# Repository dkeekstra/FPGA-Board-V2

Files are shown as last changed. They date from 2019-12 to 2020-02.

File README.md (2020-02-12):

# FPGA Board V2
## Key Features:
* Intel Cyclone 10 
* 16k logic elements
* Onboard usb programmer
* 3x 2.5khz to 200MHz programmable clock
* 4Mb on board configuration memory
* 40pin GPIO header
* USB OTG and HDMI connector
* RS485
* 8x User leds
* 5x User push buttons
* 4x User dip switches

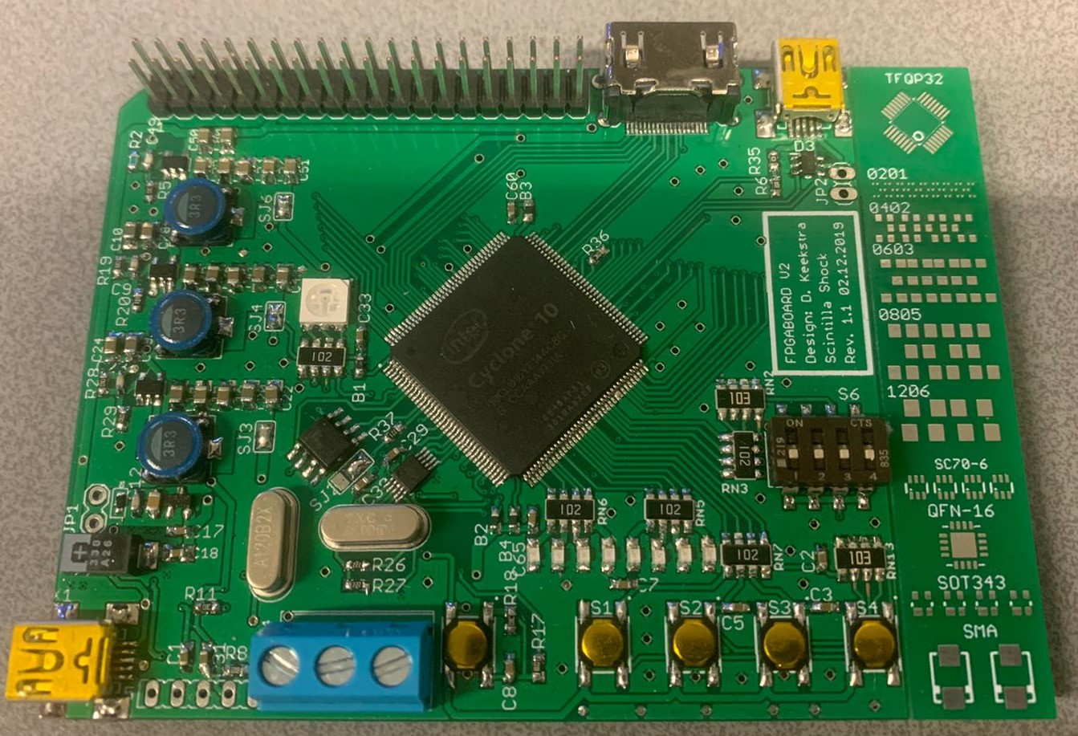
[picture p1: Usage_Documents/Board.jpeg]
FPGA BOARD


By D. Keekstra

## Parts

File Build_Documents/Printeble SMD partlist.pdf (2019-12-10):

33 | 100nF | C0603
4 | 16pF | C0603
4 | 22pF | C0603
22 | 10uF X5R | C0805K
1 | 330uF | big
1 | 100R | R0603
2 | 10 | R0603
8 | 10k | R0603
2 | 100k | R0603
2 | 1k | R0603
1 | 200R | R0603
1 | 150k | R0603
1 | 120R | R0603
1 | 32k | R0603
1 | 33k | R0603
2 | 2k2 | R0603
4 | 0 | R0603
5 | 1k | 744-8NS
2 | 10k | 744-8NS
6 | B-EU | C0603
1 | NTR2101P | SOT23-3
1 | Bi TVS 5V | SOD-523
2 | IP4234CZ6,125 | SOT95-6N
1 | OVSTRGBBCR8
9 | Any color | 0805
5 | DTSM-6 | DTSM-6
1 | OSCILLATOR 5X3 | 5X3
1 | SI5351A | MSOP-10
3 | AP3429 | TSOT-25
1 | IS25LQ040B-JNLE | SOIC8
1 | Any 3.3v rs485 | SO-08
1 | PIC18F14K50-I/SS | SOP20

SMD Partlist

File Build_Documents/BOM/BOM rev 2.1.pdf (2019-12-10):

Type | Qty | Value | Device | Package | Parts | Description | MOUSER | Discription | Stores | Price | Price Total | Checked | Order Description | Aantal Totaal | Prijs Totaal | Aantal orders
CAP | 33 | 100nF | C-EUC0603 | C0603 | C1, C2, C3, C5, C7, C8, C11, C13, C17, C27, C28, C29, C30, C31, C32, C33, C34, C35, C36, C37, C38, C39, C40, C44, C45, C46, C47, C58, C59, C60, C61, C64, C65 CAPACITOR, European symbol | 710-885012206071 | ? | 0.04 | 1.32 | x | 825 | €33.00 | 25
| 4 | 16pF | C-EUC0603 | C0603 | C4, C6, C81, C82 | CAPACITOR, European symbol | 603-CC603JRNPO0BN160 | | ? | 0.09 | 0.36 | x | | 100 | €9.00
| 4 | 22pF | C-EUC0603 | C0603 | C9, C12, C23, C49 | CAPACITOR, European symbol | 581-06035C220JAT2A | | ? | 0.18 | 0.72 | x | | 100 | €18.00
| 22 | 10uF X5R | C-EUC0805K | C0805K | C10, C14, C15, C16, C18, C20, C22, C24, C25, C26, C41, C42, C43, C50, C51, C52, C53, C54, C55, C78, C79, C80 CAPACITOR, European symbol | | | | x | 0 | 0 | x | | 550 | €0.00
| | | | | | | | | | | | | | 0 €0.00
Cap Pol | 1 | 330uF 10V (10tpe330m) | CPOL-EUD/7343-31W | D/7343-31W | C21 | POLARIZED CAPACITOR, European symbol | | | x | 0 | 0 | x | | 25 | €0.00
| | | | | | | | | | | | | | 0 €0.00
Resistor | 1 | 100R | R-EU_R0603 | R0603 | R35 | RESISTOR, European symbol | 754-RR0816P-101D | | ? | 0.014 | 0.014 | x | min 100st | 25 | €0.35
| 2 | 10 | R-EU_R0603 | R0603 | R21, R22 | RESISTOR, European symbol | 754-RR0816Q-100D | | ? | 0.014 | 0.028 | x | min 100st | 50 | €0.70
| 8 | 10k | R-EU_R0603 | R0603 | R5, R11, R18, R24, R25, R33, R34, R36 RESISTOR, European symbol | | 603-RT0603FRE0710KL | | ? | 0.014 | 0.112 | x | min 100st | 200 | €2.80
| 2 | 100k | R-EU_R0603 | R0603 | R28, R29 | RESISTOR, European symbol | 754-RR0816P-104D | | ? | 0.014 | 0.028 | x | min 100st | 50 | €0.70
| 2 | 1k | R-EU_R0603 | R0603 | R8, R17 | RESISTOR, European symbol | 603-RT0603FRE071KL | | ? | 0.014 | 0.028 | x | min 100st | 50 | €0.70
| 1 | 200R | R-EU_R0603 | R0603 | R6 | RESISTOR, European symbol | 667-ERA-3AED201V | | ? | 0.027 | 0.027 | x | min 100st | 25 | €0.68
| 1 | 150k | R-EU_R0603 | R0603 | R19 | RESISTOR, European symbol | 667-ERA-3AED154V | | | 0.037 | 0.037 | x | min 100st | 25 | €0.93
| 1 | 120R | R-EU_R0603 | R0603 | R23 | RESISTOR, European symbol | 603-RT0603DRE07120RL | | ? | 0.022 | 0.022 | x | min 100st | 25 | €0.55
| 1 | 32k | R-EU_R0603 | R0603 | R2 | RESISTOR, European symbol | 603-RT0603BRD0732KL | | | 0.211 | 0.211 | x | | 25 | €5.28
| 1 | 33k | R-EU_R0603 | R0603 | R20 | RESISTOR, European symbol | 603-RT0603DRE0733KL | | | 0.023 | 0.023 | x | min 100st | 25 | €0.58
| 2 | 2k2 | R-EU_R0603 | R0603 | R26, R27 | RESISTOR, European symbol | 603-RT0603DRE072K2L | | ? | 0.022 | 0.044 | x | min 100st | 50 | €1.10
| 4 | 0 | R-EU_R0603 | R0603 | R1, R3, R4, R12 | RESISTOR, European symbol | 71-RCS06030000Z0EA | | ? | 0.014 | 0.056 | x | min 100st | 100 | €1.40
| | | | | | | | | | | | | | 0 €0.00
Res Array | 5 | 1k | 744-8NS | 744-8NS | RN1, RN3, RN5, RN6, RN7 | CTS 744 Series | 660-CN2B4TTE102J | | | 0.151 | 0.755 | x | | 125 | €18.88
| 2 | 10k | 744-8NS | 744-8NS | RN2, RN13 | CTS 744 Series | 660-CN2B4TTE103J | | | 0.151 | 0.302 | x | | 50 | €7.55
| | | | | | | | | | | | | | 0 €0.00
Ferrite Beads | 6 | B-EU | B-EU | C0603 | B1, B2, B3, B4, B5, B6 | Standart ferrite beads 100mhz 0603 2A | 81-BLM18KG221SN1D | | | 0.09 | 0.54 | x | | 150 | €13.50
| | | | | | | | | | | | | | 0 €0.00
Coil | 3 | 3.3uH 1.9A PWR | SLF7032T3R3M1R9-2-PF | SLF7032T | L2, L3, L4 | inductor SLF7032T | SLF7032T-3R3M1R9-2-PF | | x | | 0 | | | 75 | €0.00
| | | | | | | | | | | | | | 0 €0.00
Xtal | 1 | 12MHz | XTAL/S | QS | Q1 | CRYSTAL | 549-CYS6Q31C-12MHZ | | | 0.9 | 0.9 | x | | 25 | €22.50
| 1 | 25MHz | XTAL/S | QS | Q2 | CRYSTAL | 717-9B-25.000MBBK-B | | | 0.26 | 0.26 | x | | 25 | €6.50
| | | | | | | | | | | | | | 0 €0.00
Mosfet | 1 | NTR2101P | MOSFET-PCHANNELIRLML2244 | SOT23-3 | Q3 | Generic PMOSFET | 863-NTR2101PT1G | | | 0.33 | 0.33 | x | | 25 | €8.25
| | | | | | | | | | | | | | 0 €0.00
TVS | 1 | Bi TVS 5V | DIODESOD-523 | SOD-523 | D1 | Diode | 750-CPDH5V0P-HF | | | 0.25 | 0.25 | x | | 25 | €6.25
| 2 | IP4234CZ6,125 | IP4234CZ6,125 | SOT95P275X110-6N | D2, D3 | TVS DIODE 5.5VWM 6TSOP | 771-IP4234CZ6125 | | | 0.35 | 0.7 | x | | 50 | €17.50
| | | | | | | | | | | | | | 0 €0.00
Leds | 1 | OVSTRGBBCR8 | OVSTRGBBCR8 | 150505M173300 | LED9 | RGB Wurth Elektronik led | 710-150505M173300 | | | 0.522 | 0.522 | x | | 25 | €13.05
| 9 | Any color | LEDCHIP-LED0805 | CHIP-LED0805 | LED0, LED1, LED2, LED3, LED4, LED5, LED6, LED7, USB_BLASTER LED | | 604-AP2012HD | | | 0.18 | 1.62 | x | | 225 | €40.50
| | | | | | | | | | | | | | 0 €0.00
Headers | 1 | | PINHD-1X2 | 1X02 | JP2 | PIN HEADER | | Not Placed | x | | 0 | x | | 25 | €0.00
| 1 | GPIO Header | MA20-2 | MA20-2 | SV1 | PIN HEADER | 649-68691-440HLF | | | 0.99 | 0.99 | x | | 25 | €24.75
| 1 | Pickit2 | MA06-1 | MA06-1 | SV3 | PIN HEADER | | Not Placed | | | 0 | x | | 25 | €0.00
| 1 | VIN | M02JST-PTH-VERT | JST-2-PTH-VERT | JP1 | Standard 2-pin 0.1 header. Use with" | | Not Placed | | | 0 | x | | 25 | €0.00
| | | | | | | | | | | | | | 0 €0.00
Switches | 5 | DTSM-6 | DTSM-6 | DTSM-6 | RESET, S1, S2, S3, S4 | | 611-PTS526SM08SMTR2L | | | 0.099 | 0.495 | x | | 125 | €12.38
| 1 | SWS004 | SWS004 | SMS-004 | S6 | SMD Dip Switch 4 pol. | 774-219-4LPS | | | 0.648 | 0.648 | x | | 25 | €16.20
| | | | | | | | | | | | | | 0 €0.00
Connectors | 1 | | W237-3E | W237-3E | RS485 | WAGO SREW CLAMP | 538-39880-4303 | | | 0.819 | 0.819 | x | | 25 | €20.48
| 2 | MINI-USB-32005-201 | MINI-USB-32005-201 | 32005-201 | X2, X3 | MINI USB-B Conector | 490-UJ2-MBH-1-SMT | | | 0.441 | 0.882 | x | | 50 | €22.05
| 1 | HDMI | HDMI | HDMI_A | U$9 | Horizonal HDMI type A" jack" | 649-10029449-111RLF | | | 0.648 | 0.648 | x | | 25 | €16.20
| | | | | | | | | | | | | | 0 €0.00
IC's | 1 | OSCILLATOR 5X3 | OSCILLATOR 5X3 | CRYSTAL-OSC-SMD-5X3 | U2 | Generic 5x3 and 7x5 oscillators | 972-LH535048.000000I | | | 0.9 | 0.9 | x | | 25 | €22.50
| 1 | SI5351A | SI5351A_CLOCK_GEN | MSOP-10 | U1 | CLOCK GENERATOR | 634-SI5351A-B-GT | | | 1.04 | 1.04 | x | | 25 | €26.00
| 1 | 10CL016YE144C8G | 10CL016YE144C8G | QFP50P2200X2200X165-145N | IC1 | FPGA - Field Programmable Gate Array | | | Free :) | 0 | 0 | x | | 25 | €0.00
| 3 | AP3429 | AP3429 | TSOT-25 | U$3, U$7, U$11 | Switch Power | 621-AP3429AKTTR-G1 | | | 0.369 | 1.107 | x | | 75 | €27.68
| 1 | IS25LQ040B-JNLE | IS25LQ040B-JNLE | SOIC8 | U4 | FPGA Flash | 870-25LQ040BJNLE | | | 0.333 | 0.333 | x | | 25 | €8.33
| 1 | Any 3.3v rs485 | SN65176D | SO-08 | IC2 | DIFFERENTIAL BUS TRANSCEIVER | 511-ST3485EIDT | | | 1.65 | 1.65 | x | | 25 | €41.25
| 1 | PIC18F14K50-I/SS | PIC18F14K50-I/SS | SOP65P780X200-20N | U3 | Flash Microcontrollers | 579-PIC18F14K50-I/SS | | | 2 | 2 | x | | 25 | €50.00
| | | | | | | | | | | | | | 0 €0.00
| | | | | | | | | | | 0 | | | 0 | €0.00
Misc | 1 | PCB | | | | | | | | 0 | 0 | x | | 25 | €0.00
| 1 | USB Cable | | | | | 530-SC-2ANK003F | | ? | 1.94 | 1.94 | x | | 25 | €48.50
| 5 | Bumper | | | | | 517-SJ-5003GY | | | 0.099 | 0.495 | | | 125 | €12.38
| | | | | | | | | | Total | 23.156 | | | | €578.90

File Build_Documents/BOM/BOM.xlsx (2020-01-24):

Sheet: Sorted Full BOM
Type | Qty | Value | Device | Package | Parts | Description | MOUSER | Discription | Stores | Price | Price Total | Checked | Order Description | Aantal Totaal | Prijs Totaal | Aantal orders
CAP | 33 | 100nF | C-EUC0603 | C0603 | C1, C2, C3, C5, C7, C8, C11, C13, C17, C27, C28, C29, C30, C31, C32, C33, C34, C35, C36, C37, C38, C39, C40, C44, C45, C46, C47, C58, C59, C60, C61, C64, C65 | CAPACITOR, European symbol |  |  | Tray7 4a | 0 | 0 | x |  | 825 | €0.00 | 25
 | 4 | 16pF | C-EUC0603 | C0603 | C4, C6, C81, C82 | CAPACITOR, European symbol |  |  | Tray5 7a | 0 | 0 | x |  | 100 | €0.00
 | 4 | 22pF | C-EUC0603 | C0603 | C9, C12, C23, C49 | CAPACITOR, European symbol |  |  | Tray5 9a | 0 | 0 | x |  | 100 | €0.00
 | 22 | 10uF X5R | C-EUC0805K | C0805K | C10, C14, C15, C16, C18, C20, C22, C24, C25, C26, C41, C42, C43, C50, C51, C52, C53, C54, C55, C78, C79, C80 | CAPACITOR, European symbol |  |  | Tray7 5h | 0 | 0 | x |  | 550 | €0.00
 |  |  |  |  |  |  |  |  |  |  |  |  |  | 0 | €0.00
Cap Pol | 1 | 330uF 10V (10tpe330m) | CPOL-EUD/7343-31W | D/7343-31W | C21 | POLARIZED CAPACITOR, European symbol |  |  | SMD rol | 0 | 0 | x |  | 25 | €0.00
 |  |  |  |  |  |  |  |  |  |  |  |  |  | 0 | €0.00
Resistor | 1 | 100R | R-EU_R0603 | R0603 | R35 | RESISTOR, European symbol |  |  | Tray3 6a | 0 | 0 | x |  | 25 | €0.00
 | 2 | 10 | R-EU_R0603 | R0603 | R21, R22 | RESISTOR, European symbol | 754-RR0816Q-100D |  |  | 0.09 | 0.18 | x |  | 50 | €4.50
 | 8 | 10k | R-EU_R0603 | R0603 | R5, R11, R18, R24, R25, R33, R34, R36 | RESISTOR, European symbol |  |  | Tray3 11a | 0 | 0 | x |  | 200 | €0.00
 | 2 | 100k | R-EU_R0603 | R0603 | R28, R29 | RESISTOR, European symbol |  |  | Tray4 4g | 0 | 0 | x |  | 50 | €0.00
 | 2 | 1k | R-EU_R0603 | R0603 | R8, R17 | RESISTOR, European symbol |  |  | Tray3 9h | 0 | 0 | x |  | 50 | €0.00
 | 1 | 200R | R-EU_R0603 | R0603 | R6 | RESISTOR, European symbol | 667-ERA-3AED201V |  |  | 0.05 | 0.05 | x |  | 25 | €1.25
 | 1 | 150k | R-EU_R0603 | R0603 | R19 | RESISTOR, European symbol | 667-ERA-3AED154V |  |  | 0.097 | 0.097 | x |  | 25 | €2.43
 | 1 | 120R | R-EU_R0603 | R0603 | R23 | RESISTOR, European symbol | 603-RT0603DRE07120 |  |  | 0.064 | 0.064 | x |  | 25 | €1.60
 | 1 | 32k | R-EU_R0603 | R0603 | R2 | RESISTOR, European symbol | RN731JTTD3202D25 |  |  | 0.151 | 0.151 | x |  | 25 | €3.77
 | 1 | 33k | R-EU_R0603 | R0603 | R20 | RESISTOR, European symbol | 754-RR0816P-333D |  |  | 0.077 | 0.077 | x |  | 25 | €1.93
 | 2 | 2k2 | R-EU_R0603 | R0603 | R26, R27 | RESISTOR, European symbol | 754-RR0816P-222D |  |  | 0.077 | 0.154 | x |  | 50 | €3.85
 | 4 | 0 | R-EU_R0603 | R0603 | R1, R3, R4, R12 | RESISTOR, European symbol |  |  | Tray3 2a | 0.014 | 0.056 | x |  | 100 | €1.40
 |  |  |  |  |  |  |  |  |  |  |  |  |  | 0 | €0.00
Res Array | 5 | 1k | 744-8NS | 744-8NS | RN1, RN3, RN5, RN6, RN7 | CTS 744 Series | 660-CN2B4TTE102J |  |  | 0.151 | 0.755 | x |  | 125 | €18.88
 | 2 | 10k | 744-8NS | 744-8NS | RN2, RN13 | CTS 744 Series | 603-YC324-JK-0710KL |  |  | 0.353 | 0.706 | x |  | 50 | €17.65
 |  |  |  |  |  |  |  |  |  |  |  |  |  | 0 | €0.00
Ferrite Beads | 6 | B-EU | B-EU | C0603 | B1, B2, B3, B4, B5, B6 | Standart ferrite beads 100mhz 0603 2A | 81-BLM18KG221SN1D |  |  | 0.09 | 0.54 | x |  | 150 | €13.50
 |  |  |  |  |  |  |  |  |  |  |  |  |  | 0 | €0.00
Coil | 3 | 3.3uH 1.9A PWR | SLF7032T3R3M1R9-2-PF | SLF7032T | L2, L3, L4 | inductor SLF7032T |  |  | SMD rol |  | 0 |  |  | 75 | €0.00
 |  |  |  |  |  |  |  |  |  |  |  |  |  | 0 | €0.00
Xtal | 1 | 12MHz | XTAL/S | QS | Q1 | CRYSTAL | 549-CYS6Q31C-12MHZ |  |  | 0.9 | 0.9 | x |  | 25 | €22.50
 | 1 | 25MHz | XTAL/S | QS | Q2 | CRYSTAL | 717-9B-25.000MBBK-B |  |  | 0.26 | 0.26 | x |  | 25 | €6.50
 |  |  |  |  |  |  |  |  |  |  |  |  |  | 0 | €0.00
Mosfet | 1 | NTR2101P | MOSFET-PCHANNELIRLML2244 | SOT23-3 | Q3 | Generic PMOSFET | 863-NTR2101PT1G |  |  | 0.33 | 0.33 | x |  | 25 | €8.25
 |  |  |  |  |  |  |  |  |  |  |  |  |  | 0 | €0.00
TVS | 1 | Bi TVS 5V | DIODESOD-523 | SOD-523 | D1 | Diode | 750-CPDH5V0P-HF |  |  | 0.261 | 0.261 | x |  | 25 | €6.53
 | 2 | IP4234CZ6,125 | IP4234CZ6,125 | SOT95P275X110-6N | D2, D3 | TVS DIODE 5.5VWM 6TSOP | 771-IP4234CZ6125 |  |  | 0.35 | 0.7 | x |  | 50 | €17.50
 |  |  |  |  |  |  |  |  |  |  |  |  |  | 0 | €0.00
Leds | 1 | OVSTRGBBCR8 | OVSTRGBBCR8 | 150505M173300 | LED9 | RGB Wurth Elektronik led | 710-150505M173300 |  |  | 0.522 | 0.522 | x |  | 25 | €13.05
 | 9 | Any color | LEDCHIP-LED0805 | CHIP-LED0805 | LED0, LED1, LED2, LED3, LED4, LED5, LED6, LED7, USB_BLASTER | LED | 604-AP2012HD |  |  | 0.108 | 0.972 | x |  | 225 | €24.30
 |  |  |  |  |  |  |  |  |  |  |  |  |  | 0 | €0.00
Headers | 1 |  | PINHD-1X2 | 1X02 | JP2 | PIN HEADER |  | Not Placed |  |  | 0 |  |  | 25 | €0.00
 | 1 | GPIO Header | MA20-2 | MA20-2 | SV1 | PIN HEADER | 649-68691-440HLF |  |  | 0.79 | 0.79 | x |  | 25 | €19.75
 | 1 | Pickit2 | MA06-1 | MA06-1 | SV3 | PIN HEADER |  | Not Placed |  |  | 0 |  |  | 25 | €0.00
 | 1 | VIN | M02JST-PTH-VERT | JST-2-PTH-VERT | JP1 | Standard 2-pin 0.1 header. Use with" |  | Not Placed |  |  | 0 |  |  | 25 | €0.00
 |  |  |  |  |  |  |  |  |  |  |  |  |  | 0 | €0.00
Switches | 5 | DTSM-6 | DTSM-6 | DTSM-6 | RESET, S1, S2, S3, S4 |  | 611-PTS526SM08SMTR2L |  |  | 0.092 | 0.46 | x |  | 125 | €11.50
 | 1 | SWS004 | SWS004 | SMS-004 | S6 | SMD Dip Switch 4 pol. | 774-219-4LPS |  |  | 0.648 | 0.648 | x |  | 25 | €16.20
 |  |  |  |  |  |  |  |  |  |  |  |  |  | 0 | €0.00
Connectors | 1 |  | W237-3E | W237-3E | RS485 | WAGO SREW CLAMP | 538-39880-4303 |  |  | 0.819 | 0.819 | x |  | 25 | €20.47
 | 2 | MINI-USB-32005-201 | MINI-USB-32005-201 | 32005-201 | X2, X3 | MINI USB-B Conector | 490-UJ2-MBH-1-SMT |  |  | 0.441 | 0.882 | x |  | 50 | €22.05
 | 1 | HDMI | HDMI | HDMI_A | U$9 | Horizonal HDMI type A" jack" | 649-10029449-111RLF |  |  | 0.648 | 0.648 | x |  | 25 | €16.20
 |  |  |  |  |  |  |  |  |  |  |  |  |  | 0 | €0.00
IC's | 1 | OSCILLATOR 5X3 | OSCILLATOR 5X3 | CRYSTAL-OSC-SMD-5X3 | U2 | Generic 5x3 and 7x5 oscillators | 972-LH535048.000000I |  |  | 0.9 | 0.9 | x |  | 25 | €22.50
 | 1 | SI5351A | SI5351A_CLOCK_GEN | MSOP-10 | U1 | CLOCK GENERATOR | 634-SI5351A-B-GT |  |  | 1.04 | 1.04 | x |  | 25 | €26.00
 | 1 | 10CL016YE144C8G | 10CL016YE144C8G | QFP50P2200X2200X165-145N | IC1 | FPGA - Field Programmable Gate Array |  |  | Free :) | 0 | 0 |  |  | 25 | €0.00
 | 3 | AP3429 | AP3429 | TSOT-25 | U$3, U$7, U$11 | Switch Power | 621-AP3429AKTTR |  |  | 0.369 | 1.107 | x |  | 75 | €27.68
 | 1 | IS25LQ040B-JNLE | IS25LQ040B-JNLE | SOIC8 | U4 | FPGA Flash | 870-25LQ040BJNLE |  |  | 0.333 | 0.333 | x |  | 25 | €8.33
 | 1 | Any 3.3v rs485 | SN65176D | SO-08 | IC2 | DIFFERENTIAL BUS TRANSCEIVER | 511-ST3485EIDT |  |  | 1.4 | 1.4 |  |  | 25 | €35.00
 | 1 | PIC18F14K50-I/SS | PIC18F14K50-I/SS | SOP65P780X200-20N | U3 | Flash Microcontrollers | 579-PIC18F14K50-I/SS |  |  | 1.89 | 1.89 |  |  | 25 | €47.25
 |  |  |  |  |  |  |  |  |  |  |  |  |  | 0 | €0.00
 |  |  |  |  |  |  |  |  |  |  | 0 |  |  | 0 | €0.00
Misc | 1 | PCB |  |  |  |  |  |  |  | 0 | 0 |  |  | 25 | €0.00
 | 1 | USB Cable |  |  |  |  | 530-SC-2ANK003F |  |  | 1.94 | 1.94 |  |  | 25 | €48.50
 | 5 | Bumper |  |  |  |  | 517-SJ-5003GY |  |  | 0.092 | 0.46 |  |  | 125 | €11.50
 |  |  |  |  |  |  |  |  |  | Total | 20.092 |  |  |  | €502.30

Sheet: Parts list
Type | Qty | Value | Package | Parts
Capacitor | 33 | 100nF | C0603 | C1, C2, C3, C5, C7, C8, C11, C13, C17, C27, C28, C29, C30, C31, C32, C33, C34, C35, C36, C37, C38, C39, C40, C44, C45, C46, C47, C58, C59, C60, C61, C64, C65
 | 4 | 16pF | C0603 | C4, C6, C81, C82
 | 4 | 22pF | C0603 | C9, C12, C23, C49
 | 22 | 10uF X5R | C0805K | C10, C14, C15, C16, C18, C20, C22, C24, C25, C26, C41, C42, C43, C50, C51, C52, C53, C54, C55, C78, C79, C80
Cap Pol | 1 | 330uF | D/7343-31W | C21
Resistor | 1 | 100R | R0603 | R35
 | 2 | 10 | R0603 | R21, R22
 | 8 | 10k | R0603 | R5, R11, R18, R24, R25, R33, R34, R36
 | 2 | 100k | R0603 | R28, R29
 | 2 | 1k | R0603 | R8, R17
 | 1 | 200R | R0603 | R6
 | 1 | 150k | R0603 | R19
 | 1 | 120R | R0603 | R23
 | 1 | 32k | R0603 | R2
 | 1 | 33k | R0603 | R20
 | 2 | 2k2 | R0603 | R26, R27
 | 4 | 0 | R0603 | R1, R3, R4, R12
Res Array | 5 | 1k | 744-8NS | RN1, RN3, RN5, RN6, RN7
 | 2 | 10k | 744-8NS | RN2, RN13
Ferrite Beads | 6 | B-EU | C0603 | B1, B2, B3, B4, B5, B6
Coil | 3 | 3.3uH 1.9A PWR | SLF7032T | L2, L3, L4
Xtal | 1 | 12MHz | QS | Q1
 | 1 | 25MHz | QS | Q2
Mosfet | 1 | NTR2101P | SOT23-3 | Q3
TVS | 1 | Bi TVS 5V | SOD-523 | D1
 | 2 | IP4234CZ6,125 | SOT95-6N | D2, D3
Leds | 1 | OVSTRGBBCR8 | 150505M173300 | LED9
 | 9 | Any color | CHIP-LED0805 | LED0, LED1, LED2, LED3, LED4, LED5, LED6, LED7, USB_BLASTER
Headers | 1 |  | 1X02 | JP2
 | 1 | GPIO Header | MA20-2 | SV1
 | 1 | Pickit2 | MA06-1 | SV3
 | 1 | VIN | JST-2-PTH-VERT | JP1
Switches | 5 | DTSM-6 | DTSM-6 | RESET, S1, S2, S3, S4
 | 1 | SWS004 | SMS-004 | S6
Connectors | 1 | Screw terminal 3p | W237-3E | RS485
 | 2 | MINI-USB | 32005-201 | X2, X3
 | 1 | HDMI | HDMI_A | U$9
IC's | 1 | OSCILLATOR 5X3 | 5X3 | U2
 | 1 | SI5351A | MSOP-10 | U1
 | 1 | 10CL016YE144C8G | QFP144 | IC1
 | 3 | AP3429 | TSOT-25 | U$3, U$7, U$11
 | 1 | IS25LQ040B-JNLE | SOIC8 | U4
 | 1 | Any 3.3v rs485 | SO-08 | IC2
 | 1 | PIC18F14K50-I/SS | SOP20 | U3
Misc | 1 | PCB
 | 1 | USB Cable
 | 5 | Bumper

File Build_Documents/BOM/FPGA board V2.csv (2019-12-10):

Qty | Value | Device | Package | Parts | Description | AVAILABILITY | B | DESCRIPTION | HEIGHT | MANUFACTURER_NAME | MANUFACTURER_PART_NUMBER | MF | MOUSER_PART_NUMBER | MOUSER_PRICE-STOCK | MP | MPN | OC_FARNELL | OC_NEWARK | PACKAGE | PRICE | PROD_ID
1 |  | FE05-1 | FE05-1 | SV1 | FEMALE HEADER |  |  |  |  |  |  |  |  |  |  |  | unknown | unknown
1 |  | LEDCHIP-LED0603 | CHIP-LED0603 | D4 | LED
1 |  | MA20-2 | MA20-2 | SV4 | PIN HEADER |  |  |  |  |  |  |  |  |  |  |  | unknown | unknown
1 |  | PINHD-1X2 | 1X02 | JP2 | PIN HEADER
1 |  | SI5351A_CLOCK_GEN | MSOP-10 | U1 | Si5351A I2C-PROGRAMMABLE ANY-FREQUENCY CMOS CLOCK GENERATOR + VCXO
3 |  | SJ | SJ | SJ3, SJ4, SJ6 | SMD solder JUMPER
1 |  | SJ2W | SJ_2 | SJ2 | SMD solder JUMPER
1 |  | W237-3E | W237-3E | RS485 | WAGO SREW CLAMP |  |  |  |  |  |  |  |  |  |  |  | unknown | unknown
4 | 0 | R-EU_R0603 | R0603 | R1, R3, R4, R12 | RESISTOR, European symbol
2 | 10 | R-EU_R0603 | R0603 | R21, R22 | RESISTOR, European symbol
1 | 100 | R-EU_R0603 | R0603 | R35 | RESISTOR, European symbol
2 | 100k | R-EU_R0603 | R0603 | R28, R29 | RESISTOR, European symbol
33 | 100nF | C-EUC0603 | C0603 | C1, C2, C3, C5, C7, C8, C11, C13, C17, C27, C28, C29, C30, C31, C32, C33, C34, C35, C36, C37, C38, C39, C40, C44, C45, C46, C47, C58, C59, C60, C61, C64, C65 | CAPACITOR, European symbol
1 | 10CL016YE144C8G | 10CL016YE144C8G | QFP50P2200X2200X165-145N | IC1 | FPGA - Field Programmable Gate Array |  |  | FPGA - Field Programmable Gate Array | 1.65mm | Intel | 10CL016YE144C8G |  | 989-10CL016YE144C8G | https://www.mouser.com/Search/Refine.aspx?Keyword=989-10CL016YE144C8G
2 | 10k | 744-8NS | 744-8NS | RN2, RN13 | CTS 744 Series
8 | 10k | R-EU_R0603 | R0603 | R5, R11, R18, R24, R25, R33, R34, R36 | RESISTOR, European symbol
22 | 10uF X5R | C-EUC0805K | C0805K | C10, C14, C15, C16, C18, C20, C22, C24, C25, C26, C41, C42, C43, C50, C51, C52, C53, C54, C55, C78, C79, C80 | CAPACITOR, European symbol
1 | 120 | R-EU_R0603 | R0603 | R23 | RESISTOR, European symbol
1 | 12MHz | XTAL/S | QS | Q1 | CRYSTAL
4 | 16pF | C-EUC0603 | C0603 | C4, C6, C81, C82 | CAPACITOR, European symbol
5 | 1k | 744-8NS | 744-8NS | RN1, RN3, RN5, RN6, RN7 | CTS 744 Series
2 | 1k | R-EU_R0603 | R0603 | R8, R17 | RESISTOR, European symbol
1 | 200 | R-EU_R0603 | R0603 | R6 | RESISTOR, European symbol
1 | 211k | R-EU_R0603 | R0603 | R19 | RESISTOR, European symbol
4 | 22pF | C-EUC0603 | C0603 | C9, C12, C23, C49 | CAPACITOR, European symbol
1 | 25MHz | XTAL/S | QS | Q2 | CRYSTAL
1 | 25R | R-EU_R0603 | R0603 | R37 | RESISTOR, European symbol
2 | 2k2 | R-EU_R0603 | R0603 | R26, R27 | RESISTOR, European symbol
3 | 3.3uH 1.9A PWR | SLF7032T3R3M1R9-2-PF | SLF7032T | L2, L3, L4
1 | 32k | R-EU_R0603 | R0603 | R2 | RESISTOR, European symbol
1 | 330uF 10V (10tpe330m) | CPOL-EUD/7343-31W | D/7343-31W | C21 | POLARIZED CAPACITOR, European symbol
1 | 47k | R-EU_R0603 | R0603 | R20 | RESISTOR, European symbol
3 | AP3429 | AP3429 | TSOT-25 | U$3, U$7, U$11
1 | Any 3.3v rs485 | SN65176D | SO-08 | IC2 | DIFFERENTIAL BUS TRANSCEIVER |  |  |  |  |  |  | TEXAS INSTRUMENTS |  |  |  | SN65176BD | 9589970 | 08F5891
6 | B-EU | B-EU | C0603 | B1, B2, B3, B4, B5, B6 | Standart ferrite beads 100mhz 0603 |  | 1.2A
1 | Bi TVS 5V | DIODESOD-523 | SOD-523 | D1 | Diode
1 | Ground pad for FPGA | MOUNT-PAD-ROUND2.8 | 2,8-PAD | H1 | MOUNTING PAD, round
1 | HDMI | HDMI | HDMI_A | U$1 | Horizonal HDMI type A" jack"
2 | IP4234CZ6,125 | IP4234CZ6,125 | SOT95P275X110-6N | D2, D3 | TVS DIODE 5.5VWM 6TSOP |  |  | TVS DIODE 5.5VWM 6TSOP | 1.1mm | Nexperia | IP4234CZ6,125 |  | 771-IP4234CZ6125 | https://www.mouser.com/Search/Refine.aspx?Keyword=771-IP4234CZ6125
1 | IS25LQ040B-JNLE | IS25LQ040B-JNLE | SOIC8 | U4
8 | LED0805 | LED0805 | CHIPLED_0805 | LED0, LED1, LED2, LED3, LED4, LED5, LED6, LED7
1 | M02LOCK | M02LOCK | 1X02_LOCK | JP1 | Standard 2-pin 0.1 header. Use with"
2 | MINI-USB-32005-201 | MINI-USB-32005-201 | 32005-201 | X1, X2 | MINI USB-B Conector |  |  |  |  |  |  |  |  |  |  |  | unknown | unknown
1 | NTR2101P | MOSFET-PCHANNELIRLML2244 | SOT23-3 | Q3 | Generic PMOSFET |  |  |  |  |  |  |  |  |  |  |  |  |  |  |  | TRANS-11153
1 | OSCILLATOR5X3_SOLDER | OSCILLATOR5X3_SOLDER | CRYSTAL-SMD-5X3_SOLDER | U2 | Generic 5x3 and 7x5 oscillators
1 | PIC18F14K50-I/SS | PIC18F14K50-I/SS | SOP65P780X200-20N | U3 | Flash Microcontrollers | Unavailable |  | PIC18 Series 768 B RAM 16 kB Flash 8-Bit Enhanced Microcontroller - SSOP-20 |  |  |  | Microchip |  |  | PIC18F14K50-I/SS |  |  |  | SSOP-20 Microchip | None
1 | RGBLED5050 | RGBLED5050 | RGBLED5050 | LED8 | For 5050 RGB LEDs, the order of the LEDs may vary from one manufacturer to another!
5 | SKQGADE010 | SKQGADE010 | SKQGAKE010 | S1, S2, S3, S4, S5 | Tact switch,SMT,SPST,with stem,2.55N o/f Stem Tactile Switch, SPST-NO 50 mA 1.5mm |  |  | Tact switch,SMT,SPST,with stem,2.55N o/f Stem Tactile Switch, SPST-NO 50 mA 1.5mm | mm | ALPS | SKQGADE010 |  | 688-SKQGAD | https://www.mouser.com/Search/Refine.aspx?Keyword=688-SKQGAD
1 | SWS004 | SWS004 | SMS-004 | S6 | SMD Dip Switch 4 pol.

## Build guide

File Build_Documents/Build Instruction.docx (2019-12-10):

# Building the FPGA Board V2

This tutorial is made with Quartus 18.1 for windows but different versions will also work. Its written for the FPGA Board V2.1 By D. Keekstra.

# 1. Preparing the program file

To program your FPGA configuration to the on the onboard memory we need to convert our SRAM object file (.sof) to an indirect configuration file (.jic).

1. Open your Quartus project in Quartus. Be sure the assembler step in Quartus has completed:

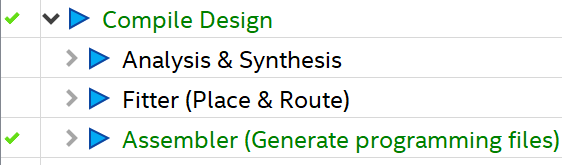
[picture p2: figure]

2. Open the conversion window by clicking File->Convert Program Files

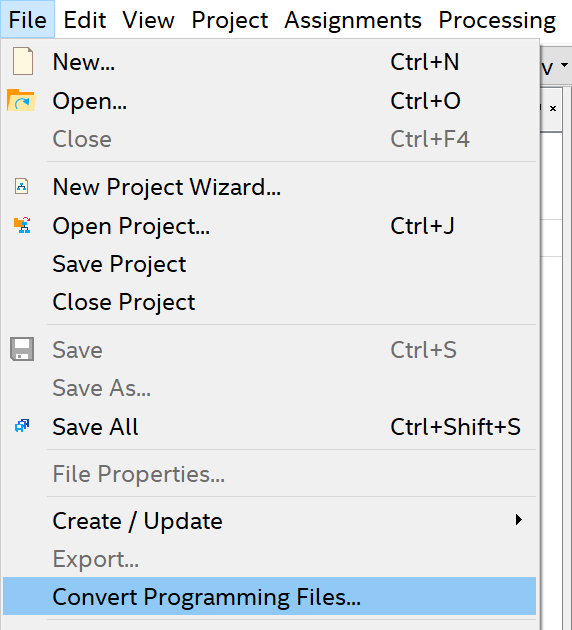
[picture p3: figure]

3. Now the conversion window will popup. Change the values according to the letters in the list

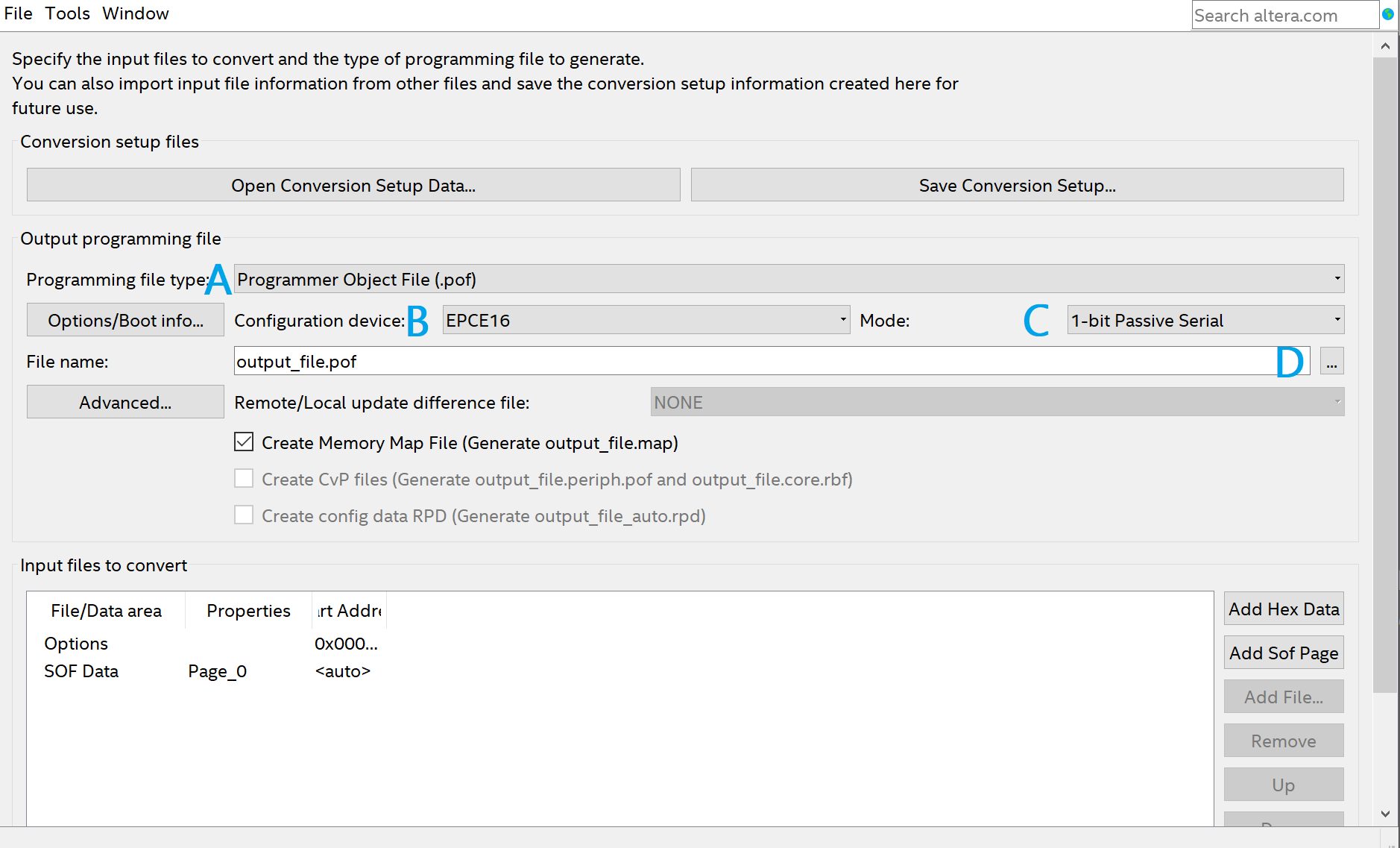
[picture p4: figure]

A. Choose JTAG Indirect Configuration File (.jic)
B. Choose EPCS4
C. Choose Active Serial
D. Select the output directory of your project. (by default in the output_files folder of your project folder)
4. Click on the Flash Loader. Than press the button Add Device..

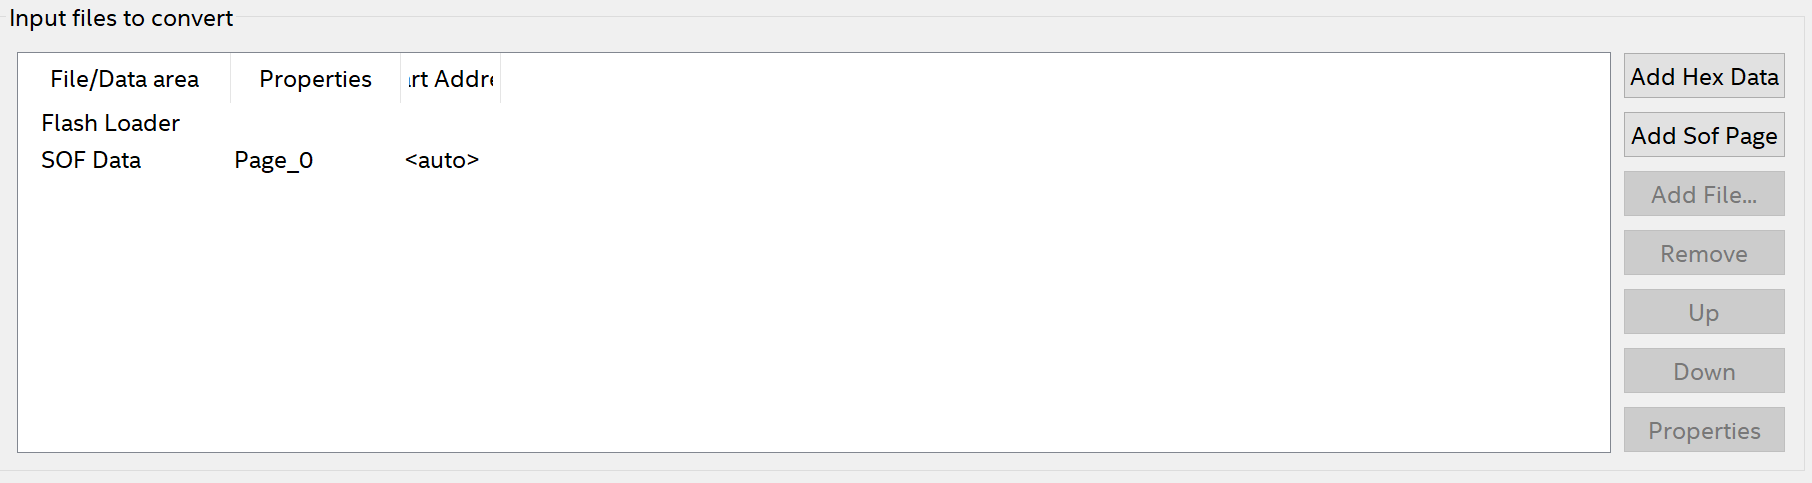
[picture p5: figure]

5. Select from the Cyclone 10 LP family the 10CL016Y and click ok.

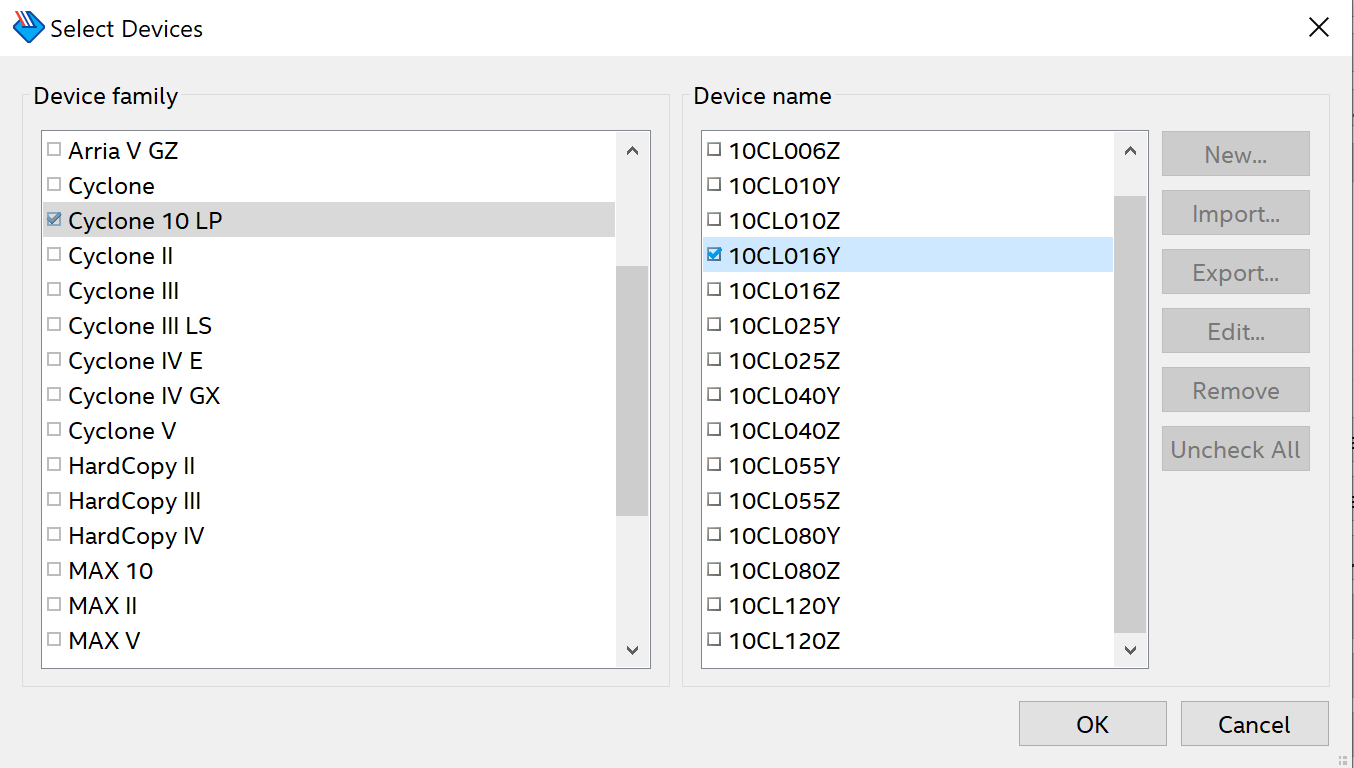
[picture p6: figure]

6. Click on SOF Data. Now click on add File.. Here you can select the .sof file from your project. (default in the output_files folder of your project)
7. The result should look like the picture below. When it does click Generate to create the .jic file.

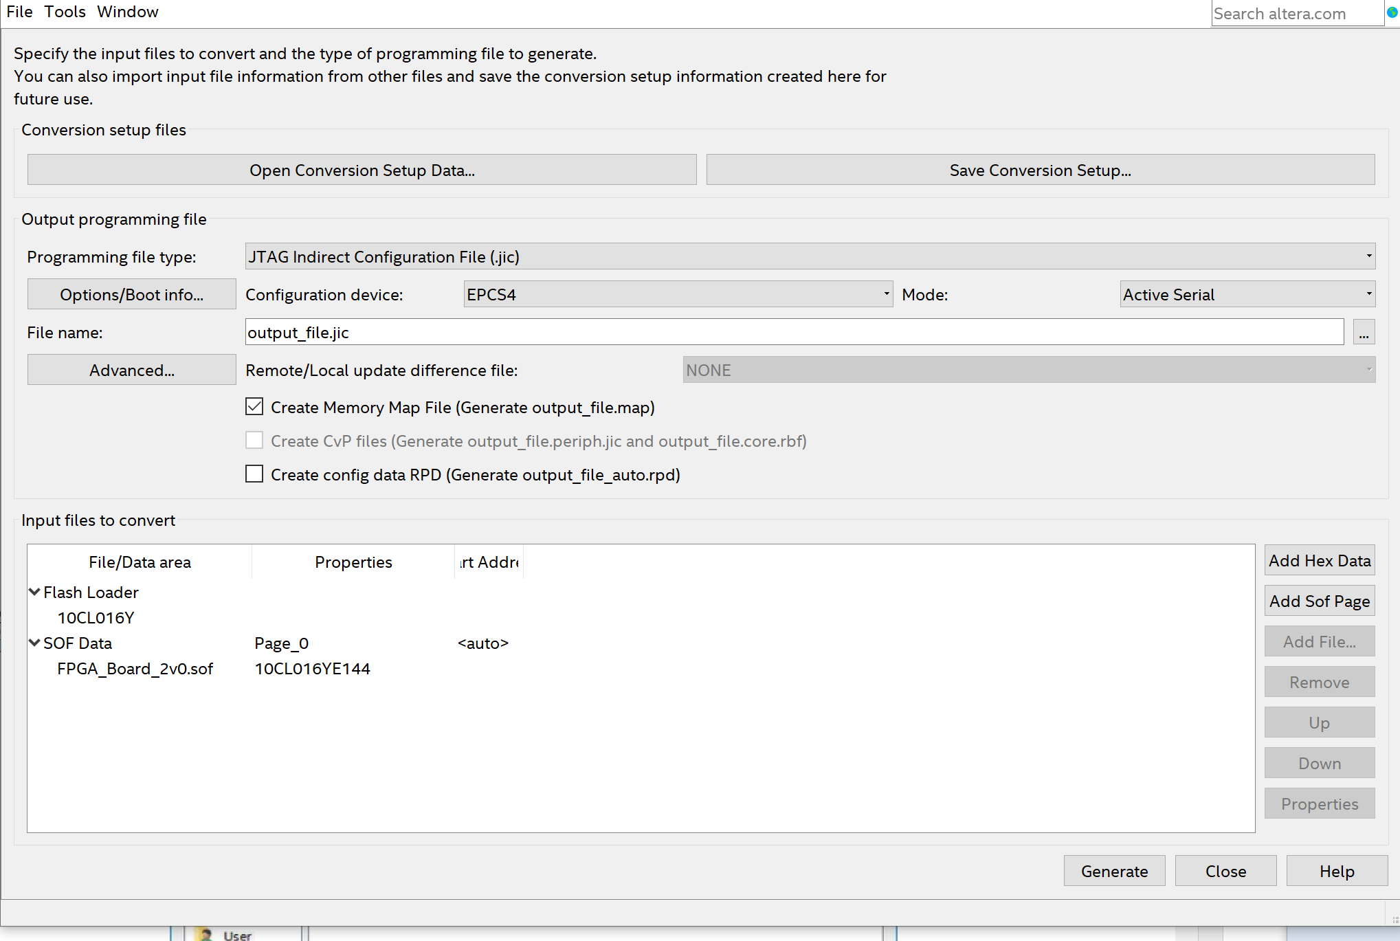
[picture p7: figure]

8. When you get the success message you can close the message and the window.

# 2. Program your device

1. Open the programmer tool in the menu under Tools->Programmer
2. The next window will open:

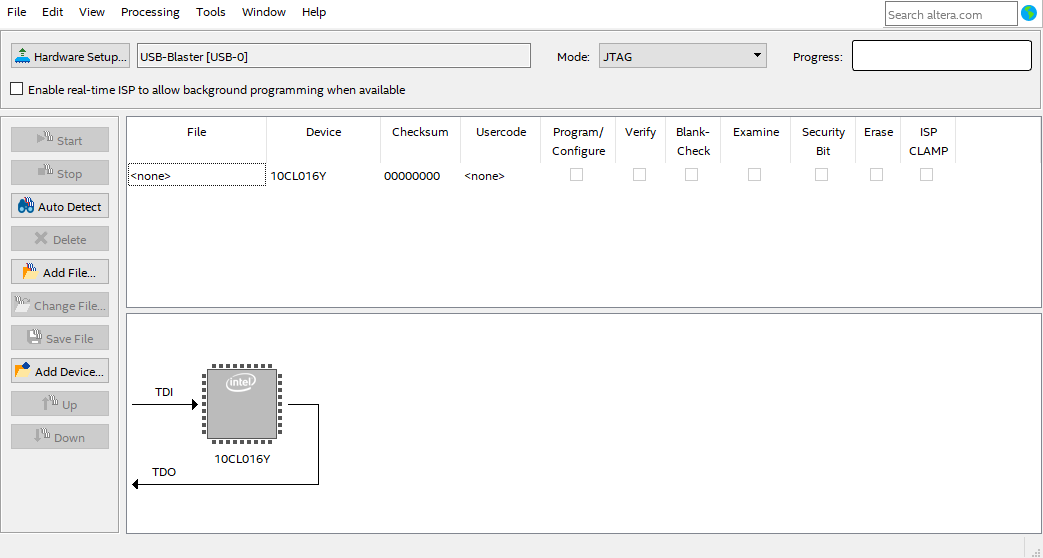
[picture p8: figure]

3. When there is no USB-Blaster next to the Hardware Setup button, Click on hardware setup and dubble click the USB-Blaster and click close

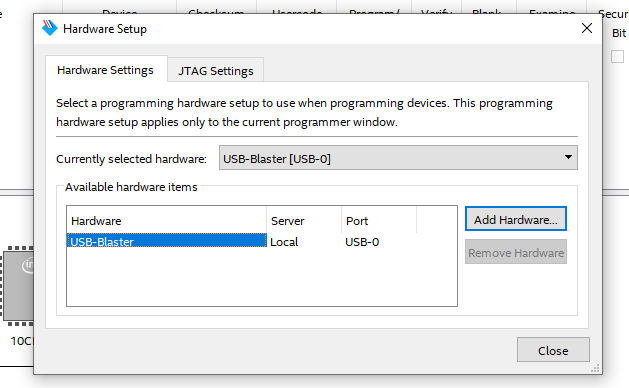
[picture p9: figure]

4. Now click the Auto detect. The USB-Blaster will detect the FPGA and you will see a screen as in in the picture of step 2.
5. Now Double click on the <none> row and select the generated jic file from part 1

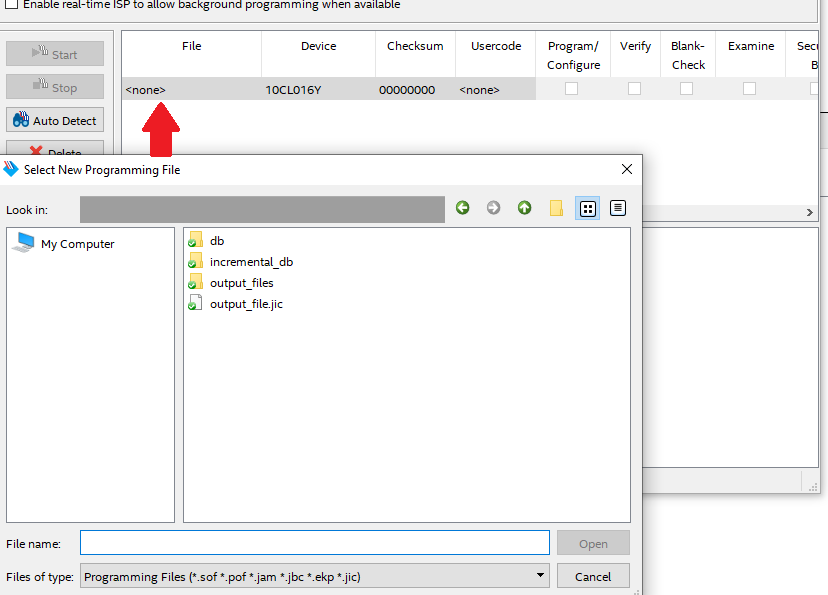
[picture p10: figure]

6. This will change the view and show a memory next to the FPGA:

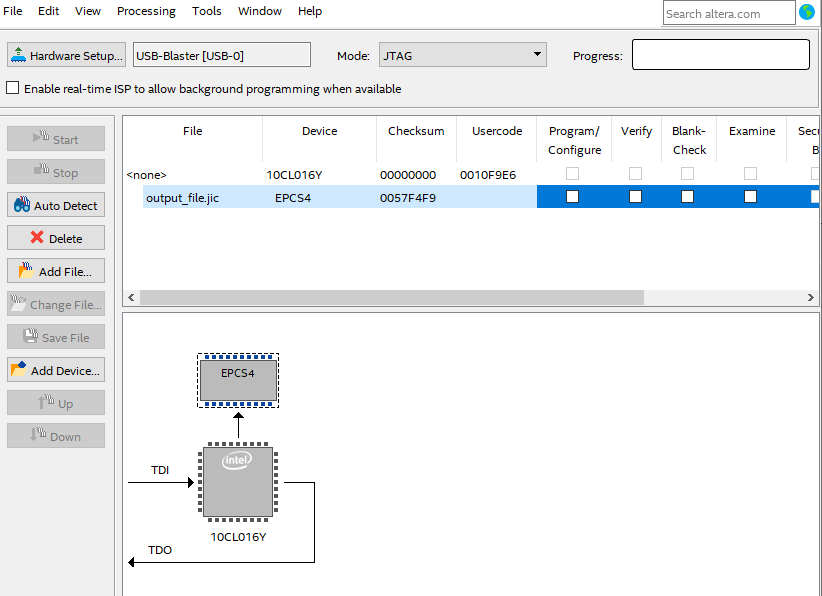
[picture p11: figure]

7. By selecting Program/Configure you can now press start to program your configuration memory.
8. For erasing deselect the Program/Configure checkbox and select the erase checkbox and press start.

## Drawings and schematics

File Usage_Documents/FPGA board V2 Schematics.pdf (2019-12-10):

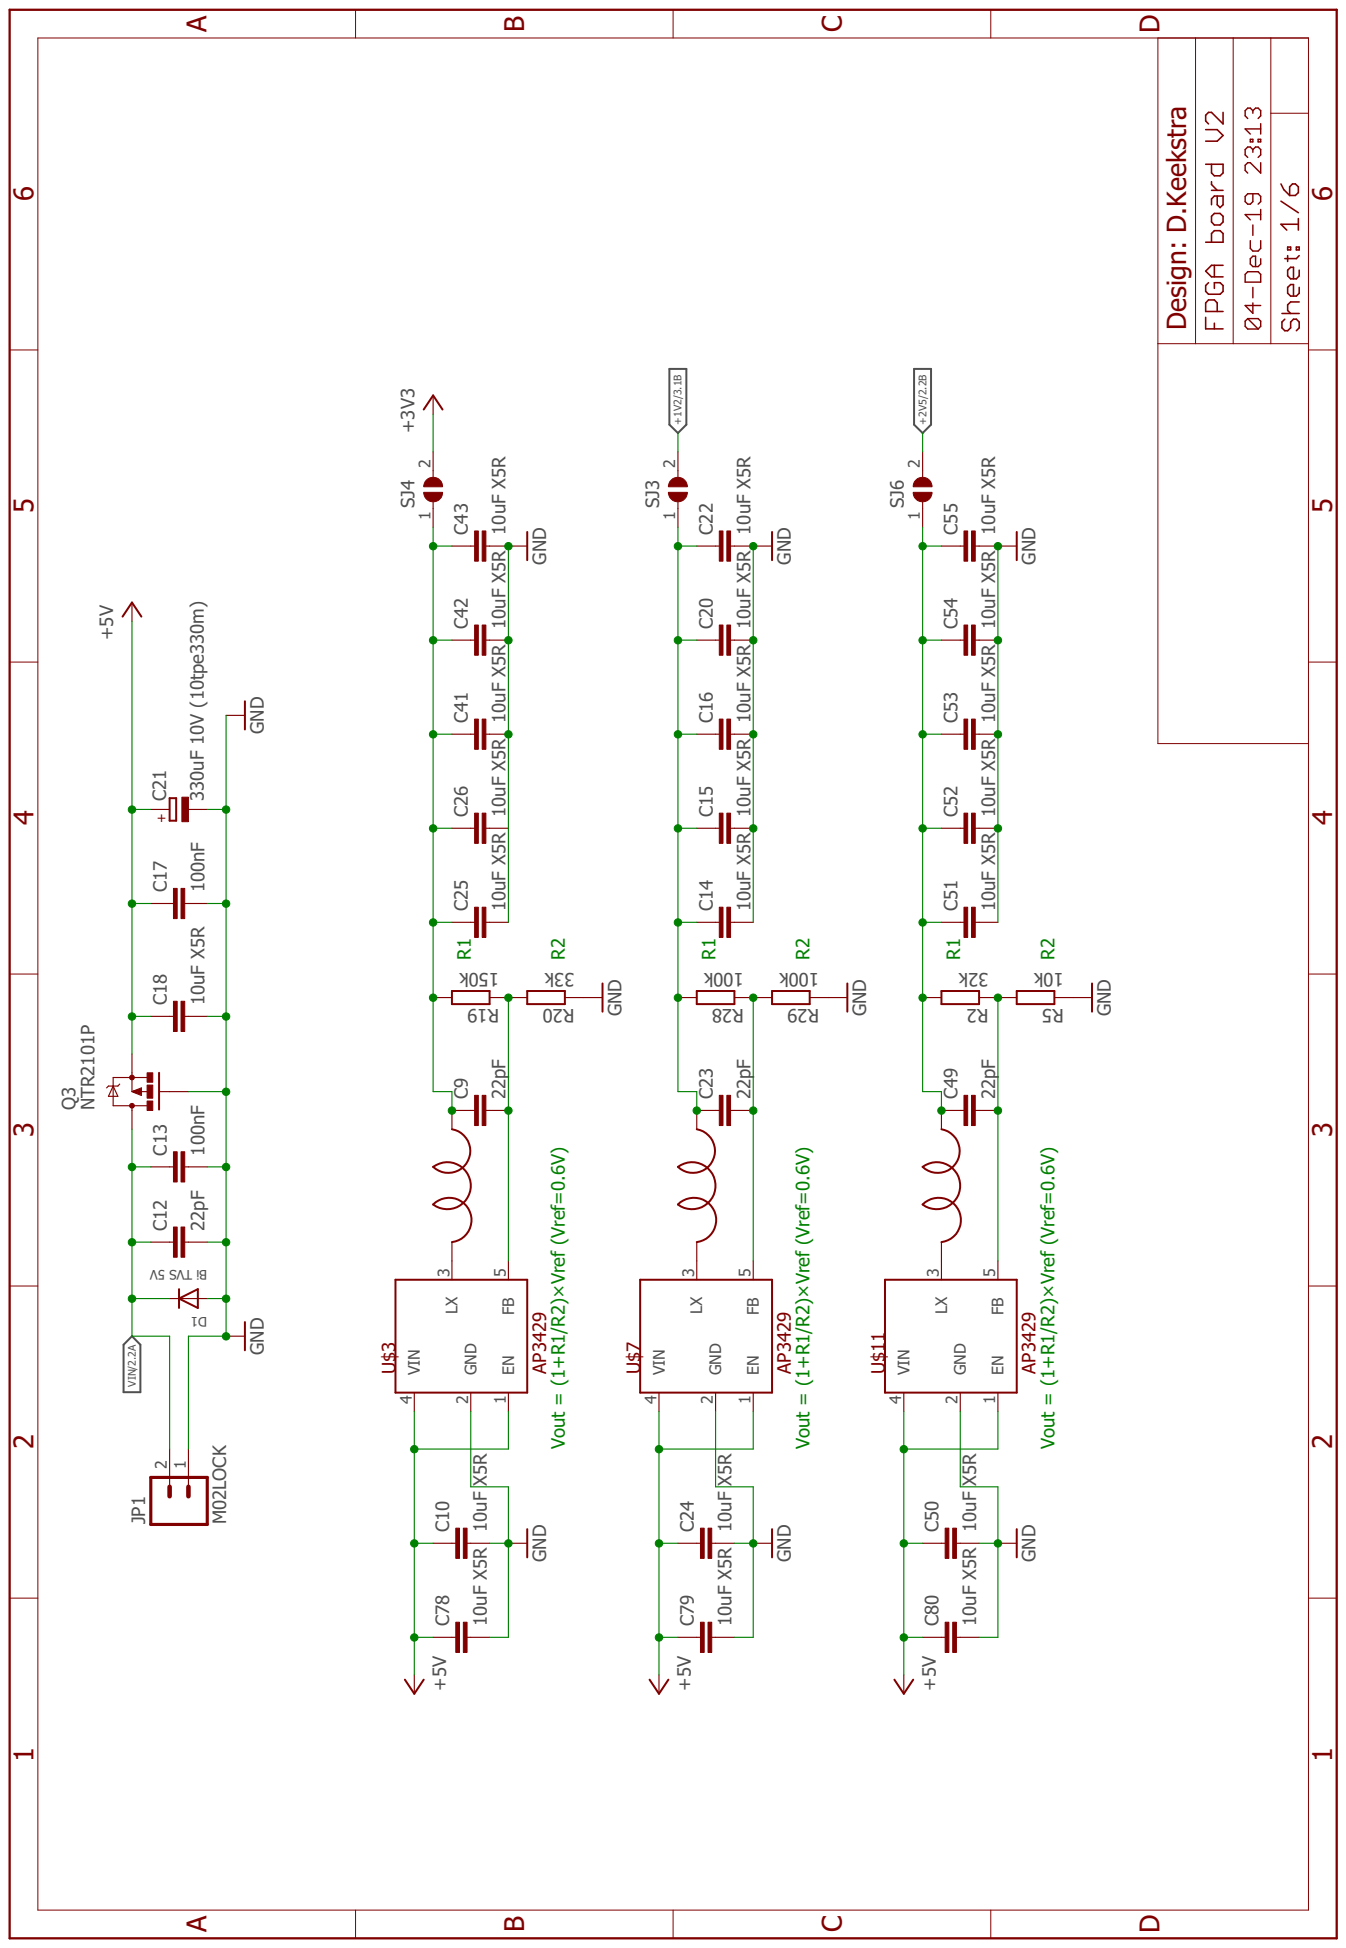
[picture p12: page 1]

22pF k051 k33 GND GND +3V3 +5V NTR2101P GND 10uF X5R 22pF 100nF V5 SVTi B100nF +5V GND 22pF k001 k001 GND GND +5V 10uF X5R 10uF X5R 330uF 10V (10tpe330m) 10uF X5R 10uF X5R 10uF X5R 10uF X5R 10uF X5R GND 10uF X5R 10uF X5R 10uF X5R 10uF X5R 10uF X5R GND 22pF k23 k01 GND GND +5V 10uF X5R 10uF X5R 10uF X5R 10uF X5R 10uF X5R 10uF X5R GND 10uF X5R 10uF X5R 10uF X5R M02LOCK EN 1 GND 2 VIN 4 FB 5 LX 3 C9 91R 02R Q3 C10 C12 C13 1D C17 EN 1 GND 2 VIN 4 FB 5 LX 3 C23 82R 92R C24 SJ3 2 1 SJ4 2 1 C18 C21 C14 C15 C16 C20 C22 C25 C26 C41 C42 C43 EN 1 GND 2 VIN 4 FB 5 LX 3 C49 2R 5R C50 SJ6 2 1 C51 C52 C53 C54 C55 C78 C79 C80 JP1 21 VIN/2.2A +1V2/3.1B +2V5/2.2B Design: D.Keekstra ABCD 1 2 3 4 5 6 ABCD 1 2 3 4 5 6 U$3 AP3429 U$7 AP3429 + U$11 AP3429 Vout = (1+R1/R2)×Vref (Vref=0.6V) R1R2 Vout = (1+R1/R2)×Vref (Vref=0.6V) R1R2 Vout = (1+R1/R2)×Vref (Vref=0.6V) R1R2

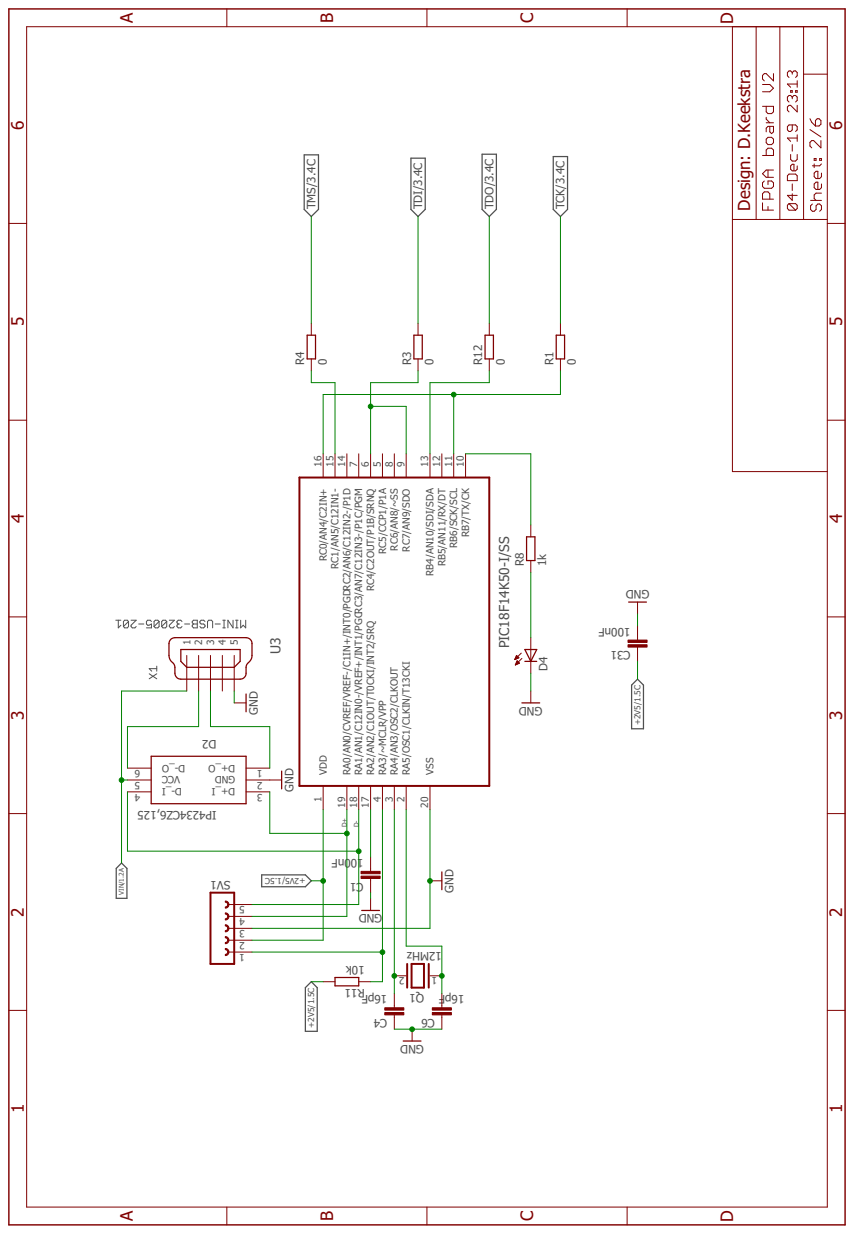
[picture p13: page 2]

12 RB6/SCK/SCL 11 RB7/TX/CK

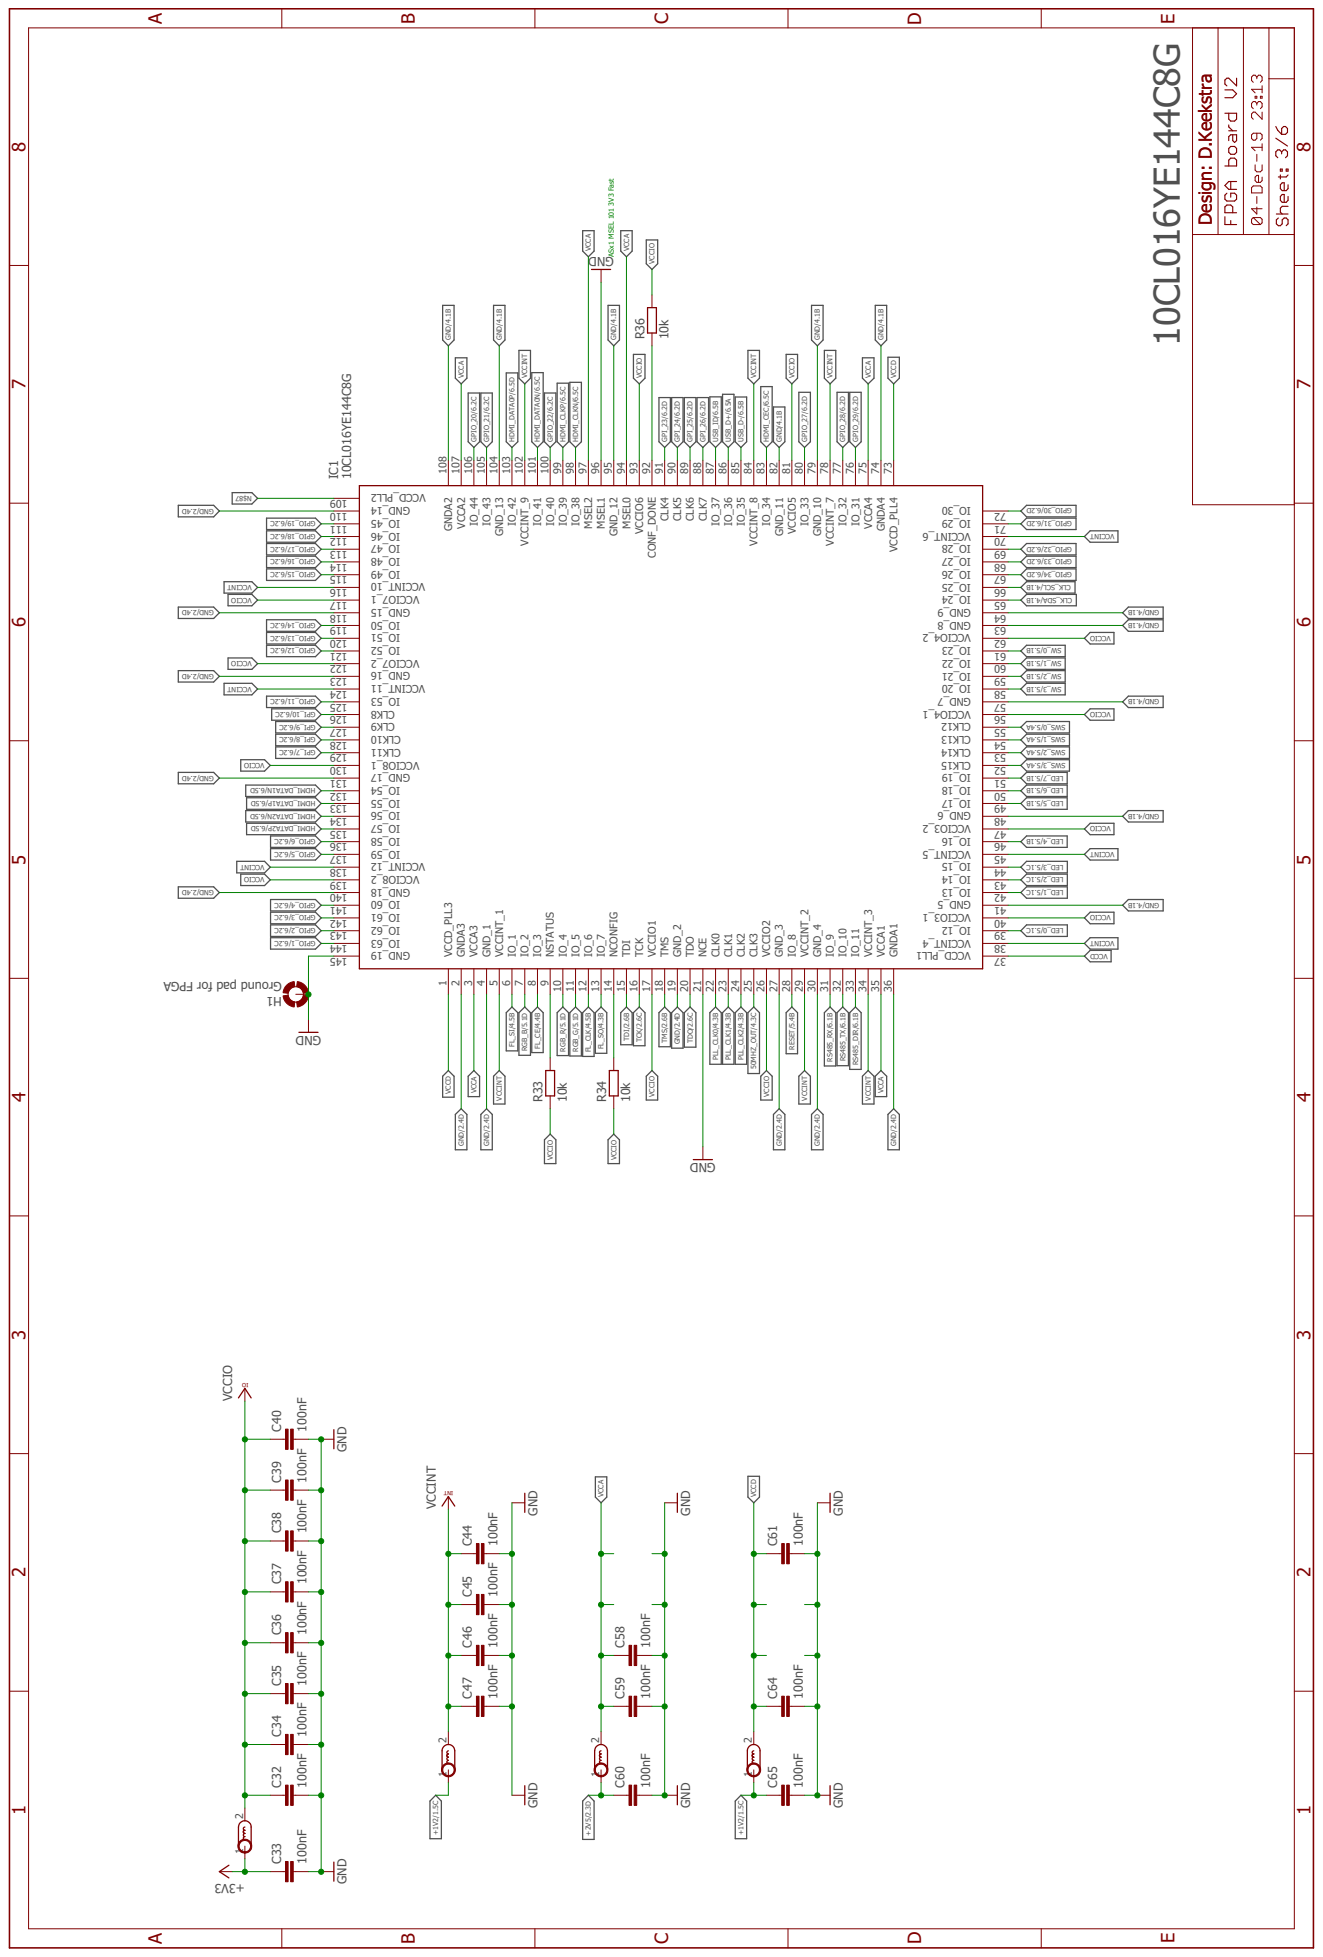
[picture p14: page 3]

10CL016YE144C8G 10CL016YE144C8G DNG AGPF r of dap dnuor G 100nF 3V3 + 100nF 100nF 100nF 100nF 100nF 100nF 100nF 100nF 10k 10k 10k DNG VCCINT 100nF 100nF 100nF 100nF VCCIO GND GND GND GND 100nF 100nF 100nF GND GND 100nF 100nF 100nF GND GND DNG IC1 VCCD_PLL3 1 GNDA3 2 VCCA3 3 GND_1 4 VCCINT_1 5 IO_1 6 IO_2 7 IO_3 8 NSTATUS 9 IO_4 10 IO_5 11 IO_6 12 IO_7 13 NCONFIG 14 TDI 15 TCK 16 VCCIO1 17 TMS 18 GND_2 19 TDO 20 NCE 21 CLK0 22 CLK1 23 CLK2 24 CLK3 25 VCCIO2 26 GND_3 27 IO_8 28 VCCINT_2 29 GND_4 30 IO_9 31 IO_10 32 IO_11 33 VCCINT_3 34 VCCA1 35 GNDA1 36 1LLP_DCCV 73 4_TNI CCV 83 21_ OI 93 1_3 OI CCV 04 5_DNG 14 31_ OI 24 41_ OI 34 51_ OI 44 5_TNI CCV 54 61_ OI 64 2_3 OI CCV 74 6_DNG 84 71_ OI 94 81_ OI 05 91_ OI 15 51KLC 25 41KLC 35 31KLC 45 21KLC 55 1_4 OI CCV 65 7_DNG 75 02_ OI 85 12_ OI 95 22_ OI 06 32_ OI 16 2_4 OI CCV 26 8_DNG 36 9_DNG 46 42_ OI 56 52_ OI 66 62_ OI 76 72_ OI 86 82_ OI 96 6_TNI CCV 07 92_ OI 17 03_ OI 27 GNDA2 108 VCCA2 107 IO_44 106 IO_43 105 GND_13 104 IO_42 103 VCCINT_9 102 IO_41 101 IO_40 100 IO_39 99 IO_38 98 MSEL2 97 MSEL1 96 GND_12 95 MSEL0 94 VCCIO6 93 CONF_DONE 92 CLK4 91 CLK5 90 CLK6 89 CLK7 88 IO_37 87 IO_36 86 IO_35 85 VCCINT_8 84 IO_34 83 GND_11 82 VCCIO5 81 IO_33 80 GND_10 79 VCCINT_7 78 IO_32 77 IO_31 76 VCCA4 75 GNDA4 74 VCCD_PLL4 73 91_DNG 541 36_ OI 441 26_ OI 341 16_ OI 241 06_ OI 141 81_DNG 041 2_8 OI CCV 931 21_TNI CCV 831 95_ OI 731 85_ OI 631 75_ OI 531 65_ OI 431 55_ OI 331 45_ OI 231 71_DNG 131 1_8 OI CCV 031 11KLC 921 01KLC 821 9KLC 721 8KLC 621 35_ OI 521 11_TNI CCV 421 61_DNG 321 2_7 OI CCV 221 25_ OI 121 15_ OI 021 05_ OI 911 51_DNG 811 1_7 OI CCV 711 01_TNI CCV 611 94_ OI 511 84_ OI 411 74_ OI 311 64_ OI 211 54_ OI 111 41_DNG 011 2LLP_DCCV 901 1H 1 2 C32 C33 C34 C35 C36 C37 C38 C39 C40 R33 R34 R36 C44 C45 C46 C47 1 2 C58 C59 1 2 C60 C61 C64 1 2 C65 GND/2.4D GND/2.4D GND/2.4D GND/2.4D GND/2.4D B1. 4/ DNG B1. 4/ DNG B1. 4/ DNG B1. 4/ DNG B1. 4/ DNG GND/4.1B GND/4.1B GND/4.1B GND/4.1B GND/4.1B GND/4.1B D4. 2/ DNG D4. 2/ DNG D4. 2/ DNG D4. 2/ DNG D4. 2/ DNG GND/2.4D VCCINT TNI CCV TNI CCV TNI CCV VCCINT VCCINT VCCINT TNI CCV TNI CCV TNI CCV VCCINT VCCINT FL_SI/4.5B FL_CE/4.4B RGB_G/5.1D RGB_B/5.1D FL_SO/4.3B TDI/2.6B TCK/2.6C TMS/2.6B TDO/2.6C PLL_CLK0/4.3B PLL_CLK1/4.3B PLL_CLK2/4.3B 50MHZ_OUT/4.3C RESET/5.4B RS485_RX/6.1B RS485_TX/6.1B RS485_DIR/6.1B D5. 6/ P2ATAD_I MDH D5. 6/ N2ATAD_I MDH D5. 6/ P1ATAD_I MDH D5. 6/ N1ATAD_I MDH C2. 6/ 9_I PG C2. 6/ 21_ OI PG C2. 6/ 31_ OI PG C2. 6/ 6_ OI PG C2. 6/ 5_ OI PG C2. 6/ 4_ OI PG C2. 6/ 3_ OI PG C2. 6/ 2_ OI PG C2. 6/ 1_ OI PG 78$N B1. 4/ ADS_KLC B1. 4/LCS_KLC HDMI_DATA0P/6.5D HDMI_DATA0N/6.5C GPIO_20/6.2C HDMI_CLKN/6.5C HDMI_CLKP/6.5C GPI_23/6.2D GPI_24/6.2D GPI_25/6.2D USB_ID/6.5B HDMI_CEC/6.5C C1. 5/ 3_DEL C1. 5/ 2_DEL C1. 5/ 1_DEL C1. 5/ 0_DEL A4. 5/ 2_S WS A4. 5/ 1_S WS A4. 5/ 0_S WS B1. 5/ 3_ WS B1. 5/ 2_ WS B1. 5/ 1_ WS B1. 5/ 0_ WS D2. 6/ 33_ OI PG D2. 6/ 23_ OI PG GPIO_29/6.2D FL_CLK/4.5B VCCIO VCCIO VCCIO VCCIO VCCIO OI CCV OI CCV OI CCV OI CCV VCCIO VCCIO OI CCV OI CCV OI CCV OI CCV +1V2/1.5C +1V2/1.5C +2V5/2.3D VCCA VCCA VCCA VCCA VCCA VCCA VCCA VCCD VCCD DCCV VCCD A4. 5/ 3_S WS D2. 6/ 13_ OI PG B1. 5/ 4_DEL B1. 5/ 5_DEL B1. 5/ 6_DEL B1. 5/ 7_DEL RGB_R/5.1D C2. 6/ 01_I PG C2. 6/ 7_I PG C2. 6/ 8_I PG C2. 6/ 11_ OI PG C2. 6/ 41_ OI PG C2. 6/ 51_ OI PG C2. 6/ 61_ OI PG C2. 6/ 71_ OI PG C2. 6/ 81_ OI PG C2. 6/ 91_ OI PG GPIO_21/6.2C GPIO_22/6.2C GPIO_27/6.2D GPIO_28/6.2D USB_D+/6.5A USB_D-/6.5B D2. 6/ 03_ OI PG GPI_26/6.2D D2. 6/ 43_ OI PG Design: D.Keekstra Design: D.Keekstra
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

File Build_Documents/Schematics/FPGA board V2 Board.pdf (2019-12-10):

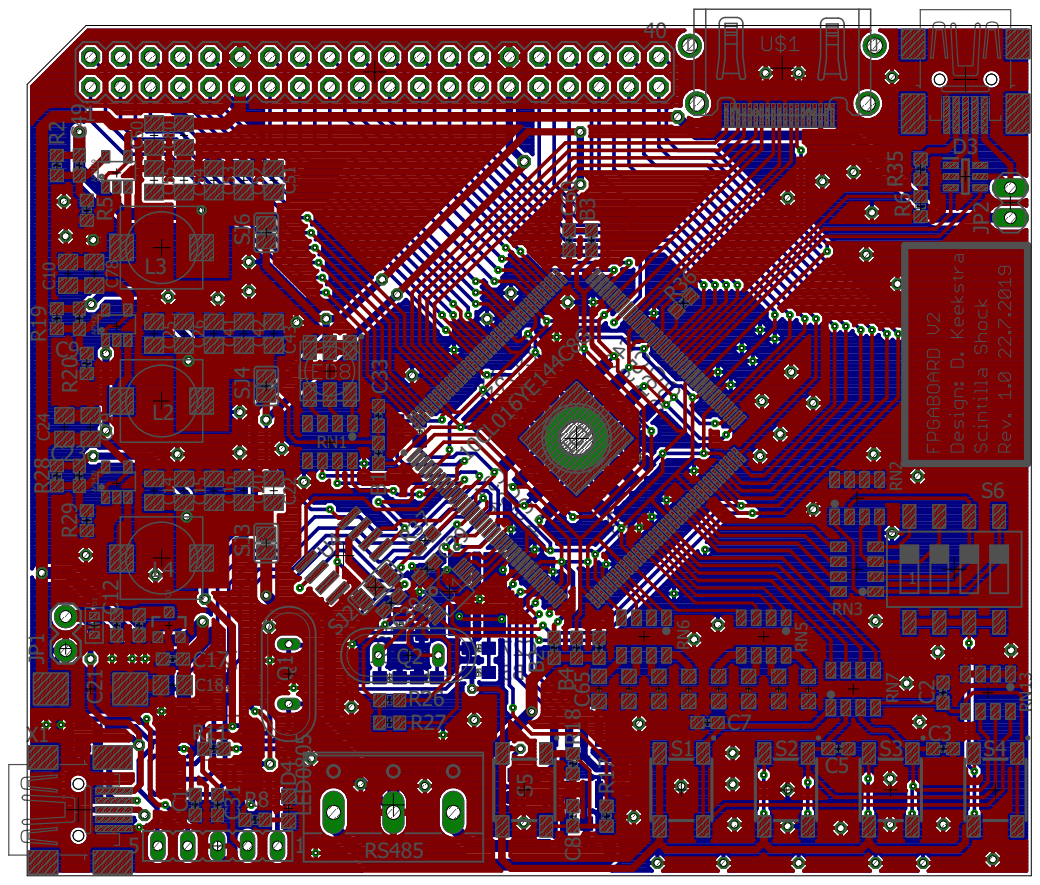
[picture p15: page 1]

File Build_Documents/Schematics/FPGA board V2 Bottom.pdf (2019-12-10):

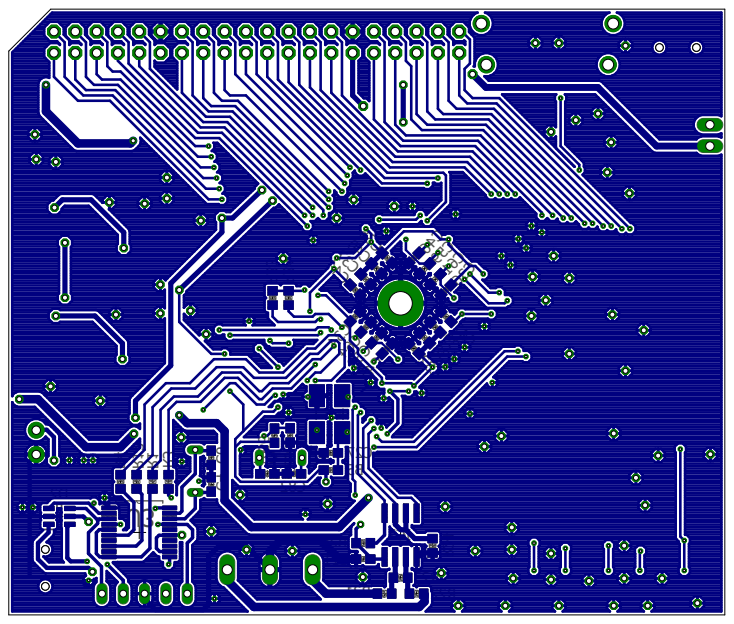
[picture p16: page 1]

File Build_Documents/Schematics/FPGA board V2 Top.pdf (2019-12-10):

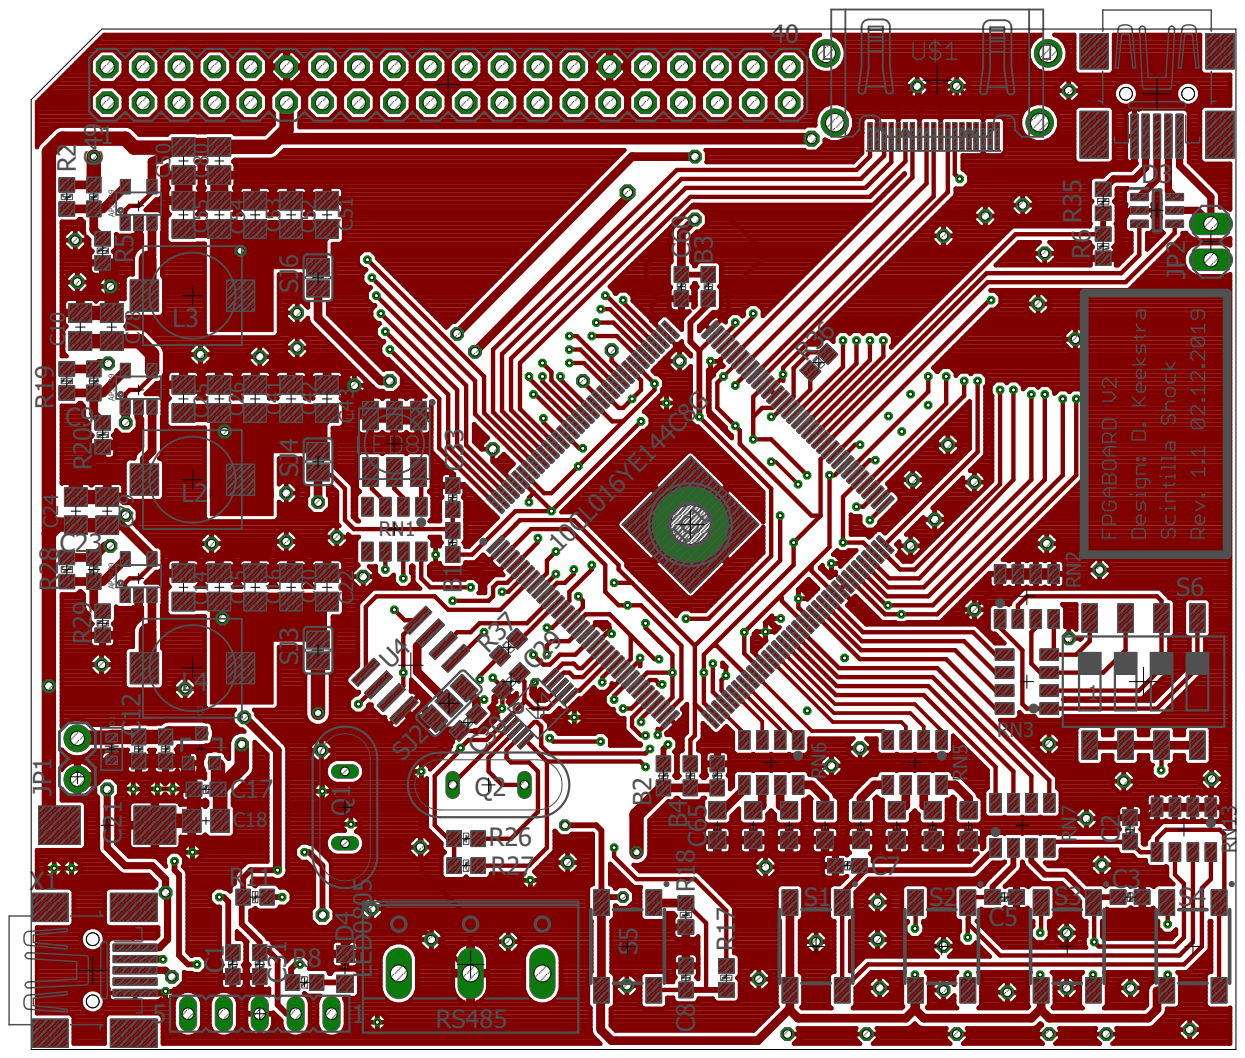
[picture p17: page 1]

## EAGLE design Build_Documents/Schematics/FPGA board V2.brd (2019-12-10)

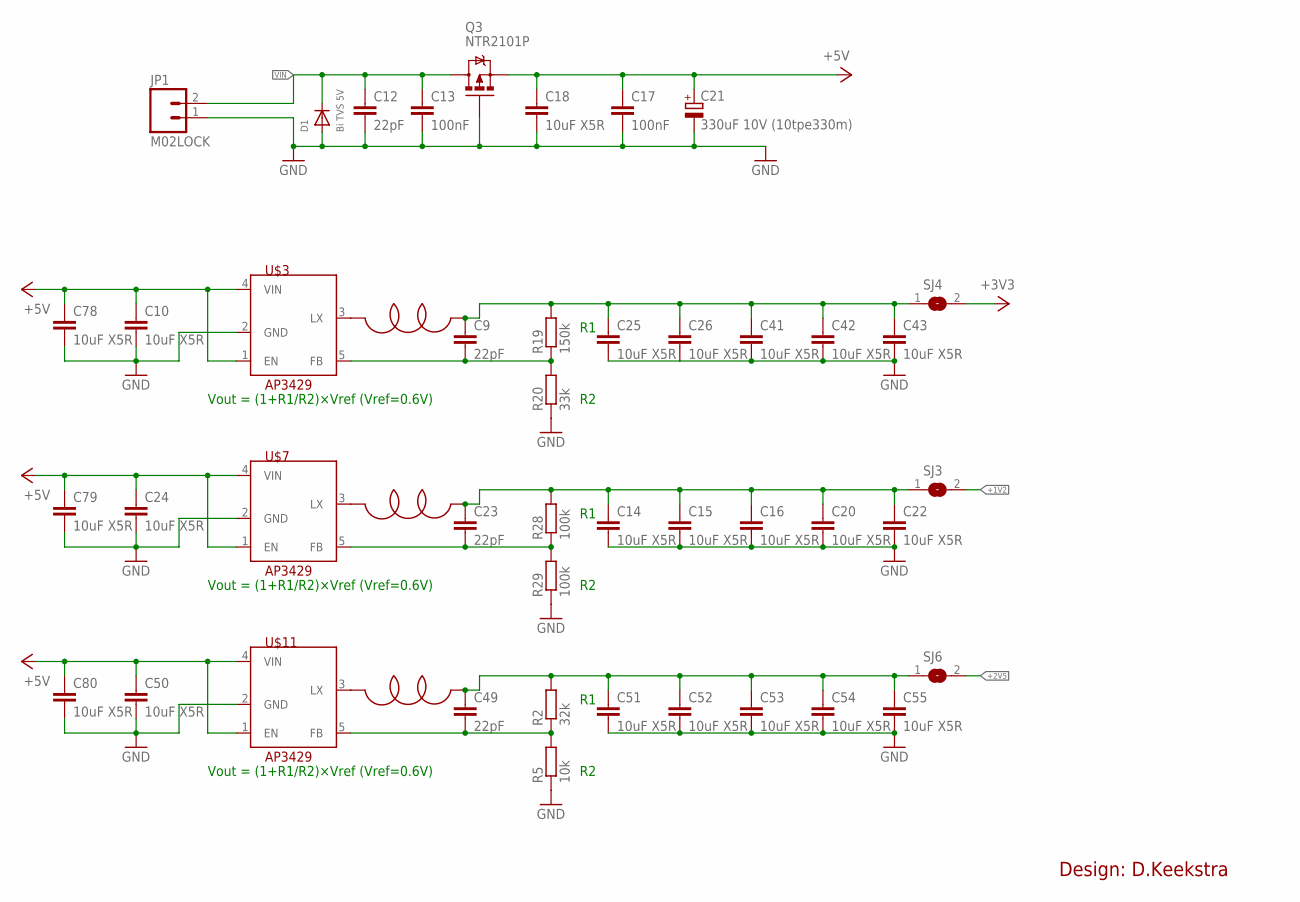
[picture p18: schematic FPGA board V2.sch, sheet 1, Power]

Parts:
C9, C12, C23, C49: 22pF; C0603
C10, C14, C15, C16, C18, C20, C22, C24, C25, C26, C41, C42, C43, C50, C51, C52, C53, C54, C55, C78, C79, C80: 10uF X5R; C0805K
C13, C17: 100nF; C0603
C21: 330uF 10V (10tpe330m); D/7343-31W
D1: Bi TVS 5V; SOD-523
JP1: M02LOCK; 1X02_LOCK
L2, L3, L4: 3.3uH 1.9A PWR; SLF7032T
Q3: NTR2101P; SOT23-3
R2: 32k; R0603
R5: 10k; R0603
R19: 150k; R0603
R20: 33k; R0603
R28, R29: 100k; R0603
SJ3, SJ4, SJ6: SJ
U$3, U$7, U$11: AP3429; TSOT-25

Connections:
+1V2: SJ3.2; also elsewhere on the board
+2V5: SJ6.2; also elsewhere on the board
+3V3: SJ4.2; also elsewhere on the board
+5V: C10.1, C17.1, C18.1, C21.+, C24.1, C50.1, C78.1, C79.1, C80.1, Q3.2 (S), U$3.1 (EN), U$3.4 (VIN), U$7.1 (EN), U$7.4 (VIN), U$11.1 (EN), U$11.4 (VIN); also elsewhere on the board
GND: C10.2, C12.2, C13.2, C14.2, C15.2, C16.2, C17.2, C18.2, C20.2, C21.-, C22.2, C24.2, C25.2, C26.2, C41.2, C42.2, C43.2, C50.2, C51.2, C52.2, C53.2, C54.2, C55.2, C78.2, C79.2, C80.2, D1.A, JP1.1, Q3.1 (G), R5.1, R20.1, R29.1, U$3.2 (GND), U$7.2 (GND), U$11.2 (GND); also elsewhere on the board
L2: C9.1, C25.1, C26.1, C41.1, C42.1, C43.1, L2.P$1, R19.2, SJ4.1
unnamed: L3.P$2, U$11.3 (LX)
unnamed: C49.1, C51.1, C52.1, C53.1, C54.1, C55.1, L3.P$1, R2.2, SJ6.1
unnamed: C49.2, R2.1, R5.2, U$11.5 (FB)
unnamed: C14.1, C15.1, C16.1, C20.1, C22.1, C23.1, L4.P$1, R28.2, SJ3.1
unnamed: C23.2, R28.1, R29.2, U$7.5 (FB)
unnamed: L2.P$2, U$3.3 (LX)
unnamed: C9.2, R19.1, R20.2, U$3.5 (FB)
unnamed: L4.P$2, U$7.3 (LX)
VIN: C12.1, C13.1, D1.K (C), JP1.2, Q3.3 (D); also elsewhere on the board

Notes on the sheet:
Vout = (1+R1/R2)×Vref (Vref=0.6V)
Design: D.Keekstra

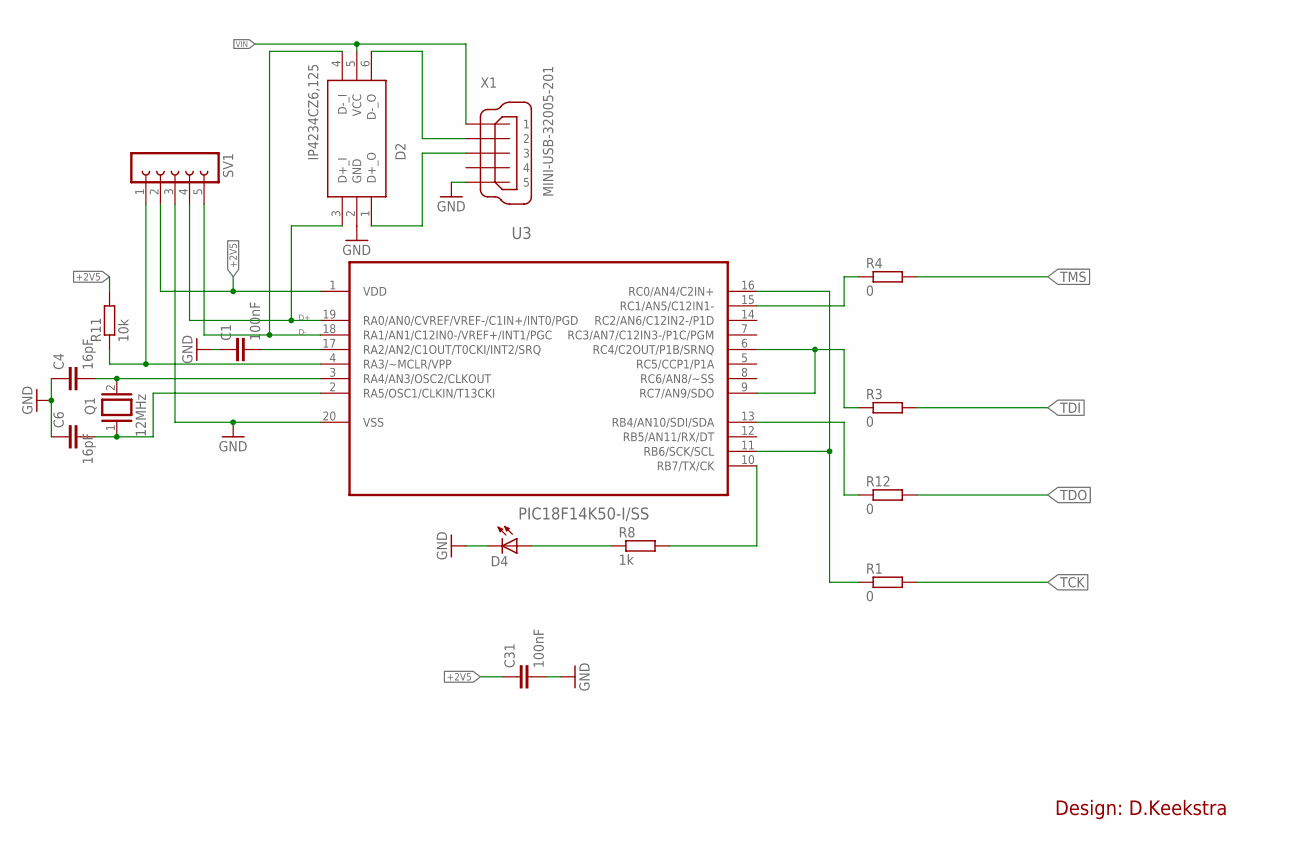
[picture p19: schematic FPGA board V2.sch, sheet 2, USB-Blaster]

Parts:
C1, C31: 100nF; C0603
C4, C6: 16pF; C0603
D2: IP4234CZ6,125; SOT95P275X110-6N
D4: LED0805; CHIPLED_0805
Q1: 12MHz; QS
R1, R3, R4, R12: 0; R0603
R8: 1k; R0603
R11: 10k; R0603
SV1: FE05-1
U3: PIC18F14K50-I/SS; SOP65P780X200-20N
X1: MINI-USB-32005-201; 32005-201

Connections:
+2V5: C31.1, R11.2, SV1.2, U3.1 (VDD); also elsewhere on the board
D+: D2.3 (D+_I), SV1.4, U3.19 (RA0/AN0/CVREF/VREF-/C1IN+/INT0/PGD)
D-: D2.4 (D-_I), SV1.5, U3.18 (RA1/AN1/C12IN0-/VREF+/INT1/PGC)
GND: C1.1, C4.1, C6.1, C31.2, D2.2 (GND), D4.C, SV1.3, U3.20 (VSS), X1.5; also elsewhere on the board
unnamed: R8.2, U3.10 (RB7/TX/CK)
unnamed: D4.A, R8.1
unnamed: R1.1, U3.11 (RB6/SCK/SCL), U3.16 (RC0/AN4/C2IN+)
unnamed: C1.2, U3.17 (RA2/AN2/C1OUT/T0CKI/INT2/SRQ)
unnamed: R4.1, U3.15 (RC1/AN5/C12IN1-)
unnamed: R11.1, SV1.1, U3.4 (RA3/~MCLR/VPP)
unnamed: R3.1, U3.6 (RC4/C2OUT/P1B/SRNQ), U3.9 (RC7/AN9/SDO)
unnamed: D2.1 (D+_O), X1.3
unnamed: R12.1, U3.13 (RB4/AN10/SDI/SDA)
unnamed: D2.6 (D-_O), X1.2
unnamed: C4.2, Q1.2, U3.3 (RA4/AN3/OSC2/CLKOUT)
unnamed: C6.2, Q1.1, U3.2 (RA5/OSC1/CLKIN/T13CKI)
TCK: R1.2; also elsewhere on the board
TDI: R3.2; also elsewhere on the board
TDO: R12.2; also elsewhere on the board
TMS: R4.2; also elsewhere on the board
VIN: D2.5 (VCC), X1.1; also elsewhere on the board

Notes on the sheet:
Design: D.Keekstra

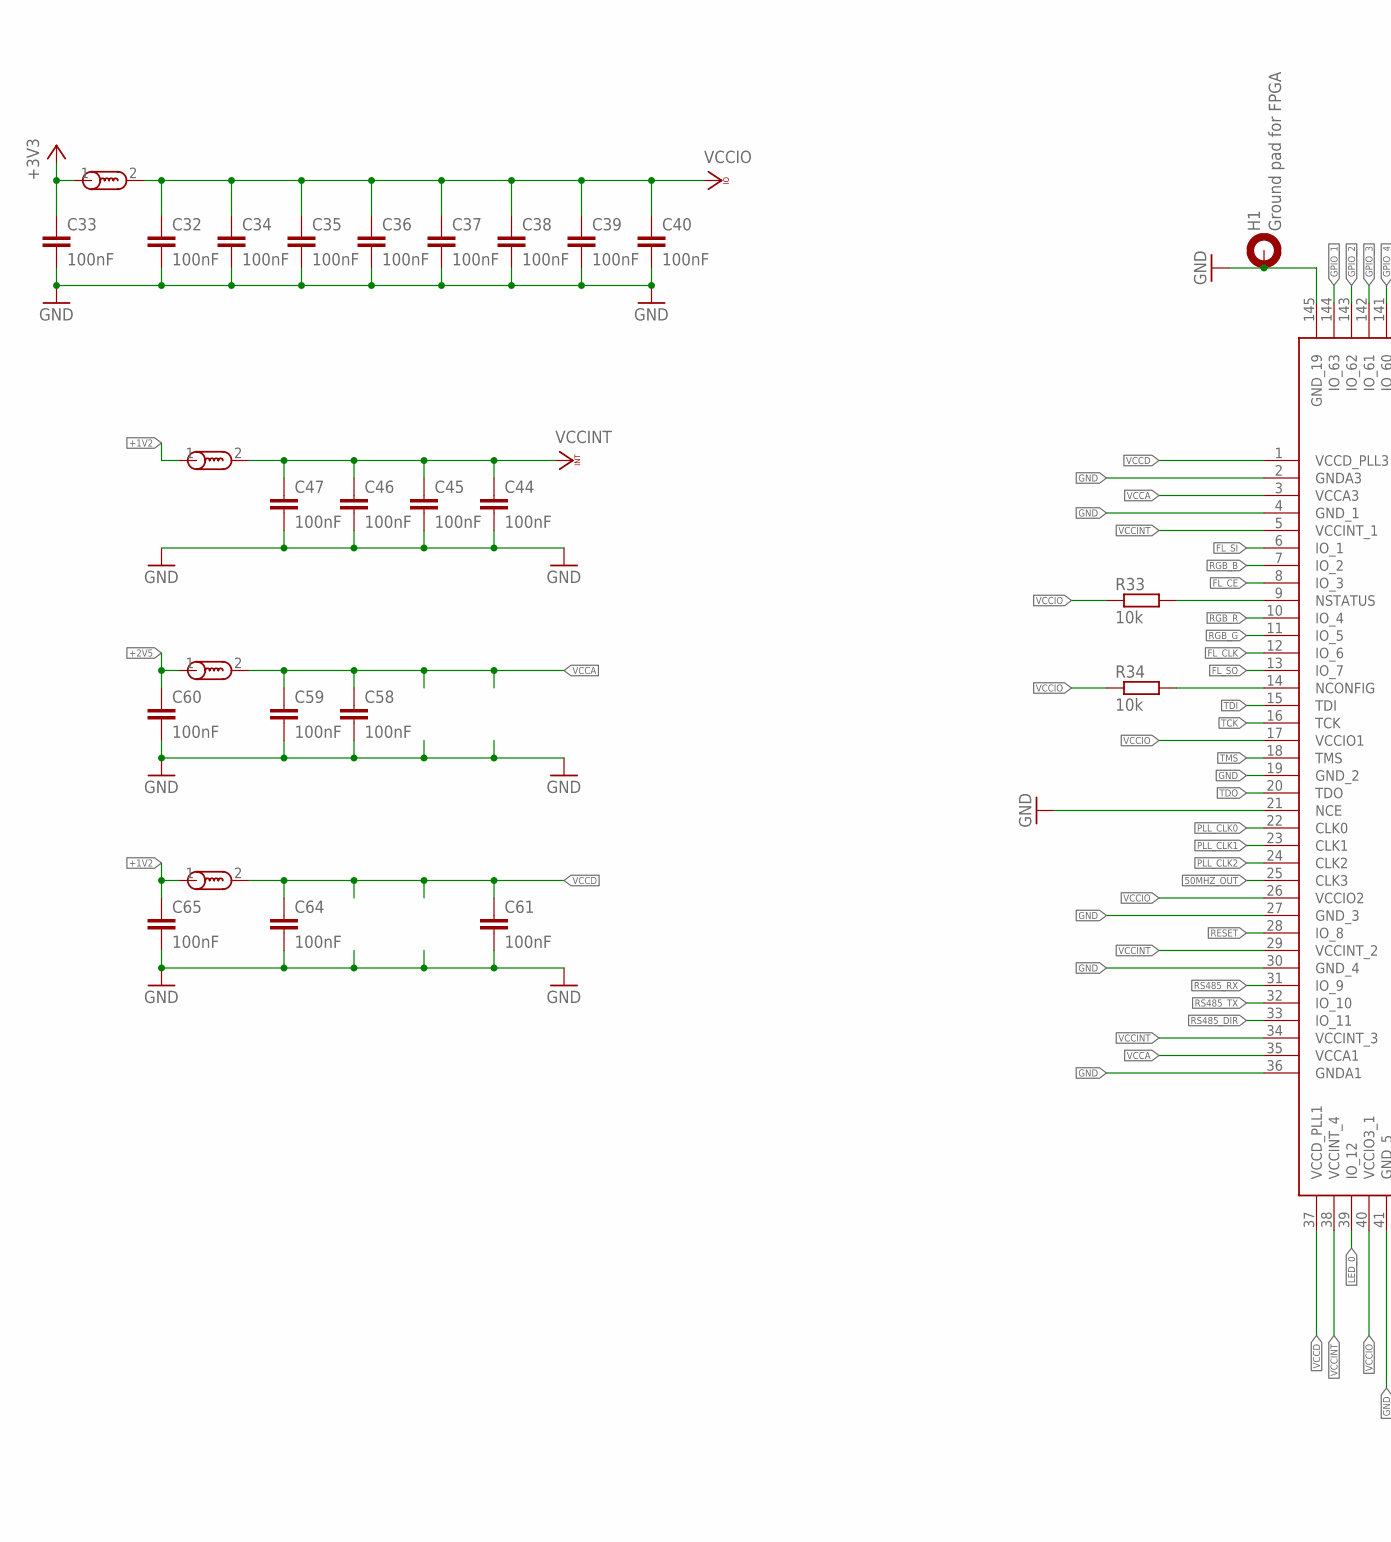
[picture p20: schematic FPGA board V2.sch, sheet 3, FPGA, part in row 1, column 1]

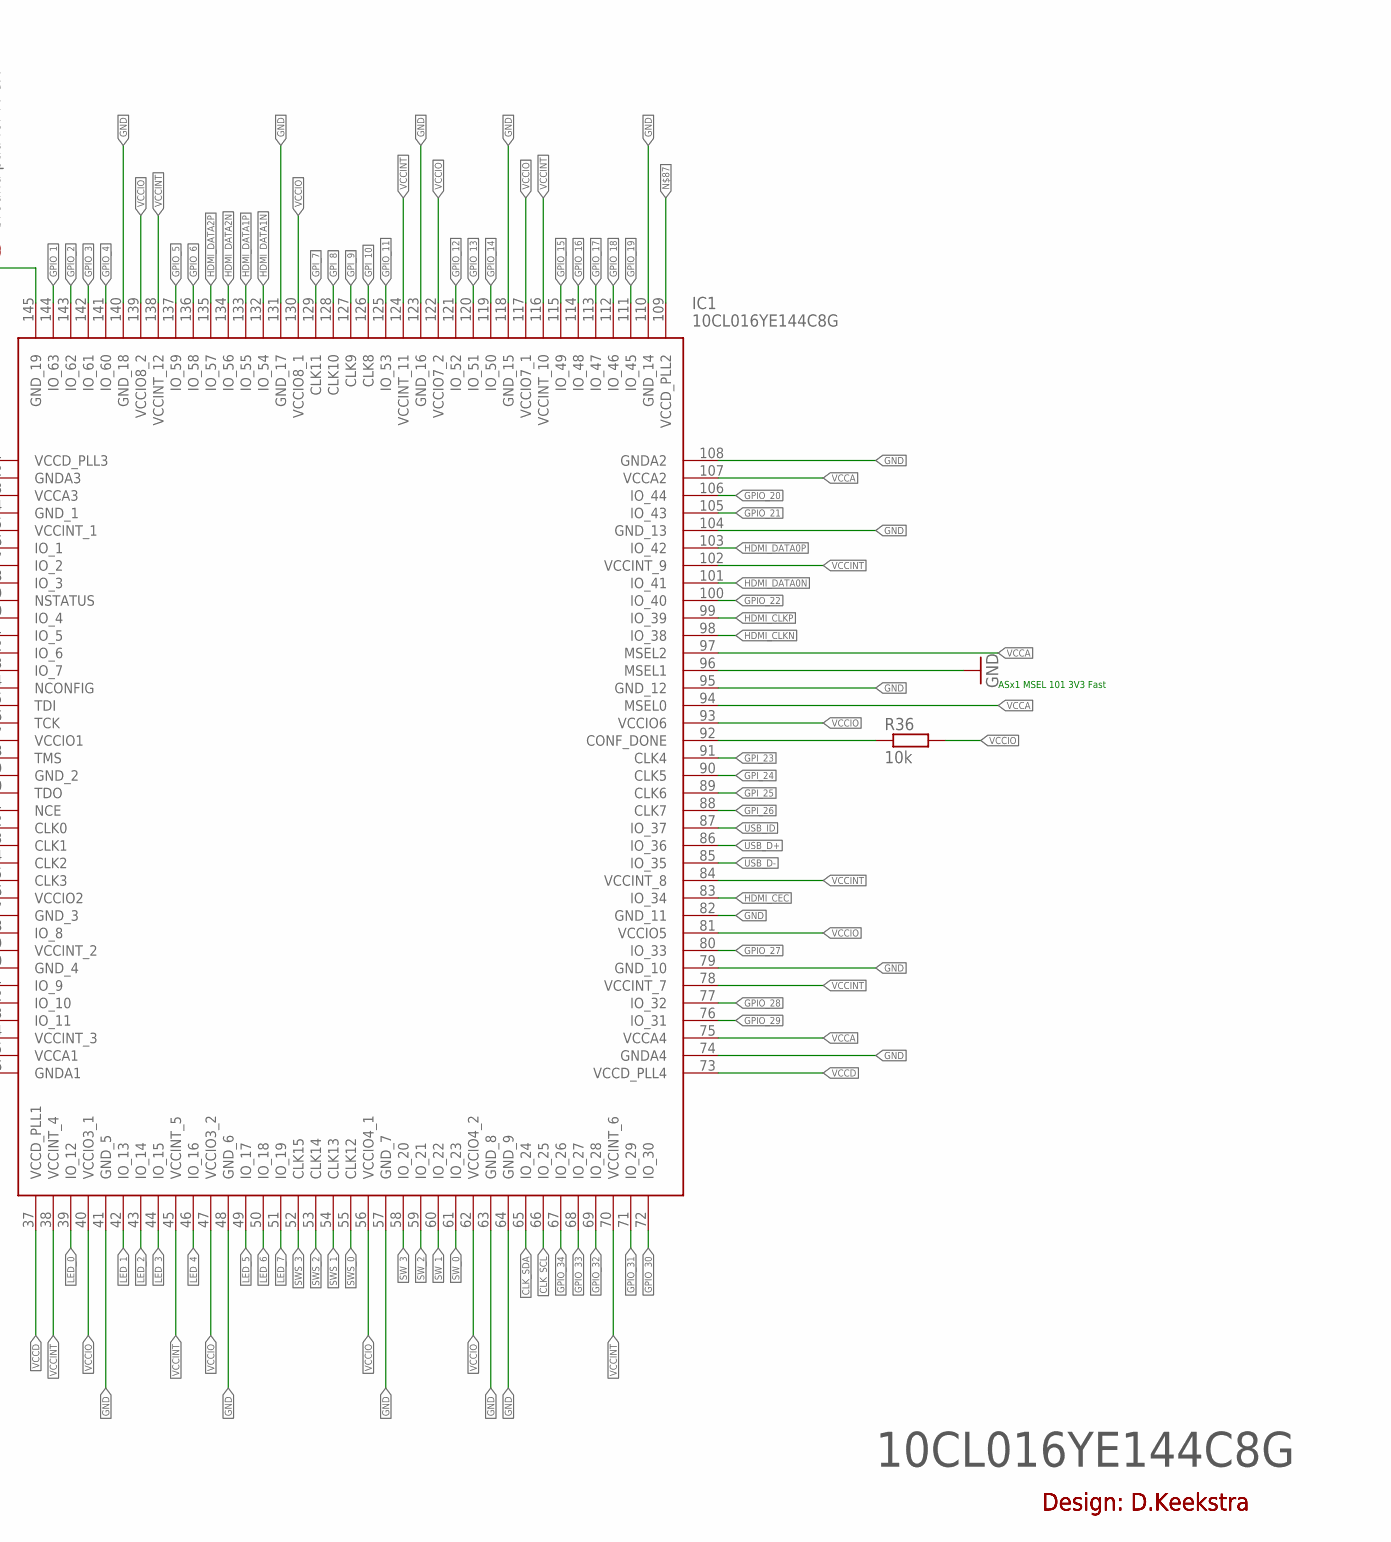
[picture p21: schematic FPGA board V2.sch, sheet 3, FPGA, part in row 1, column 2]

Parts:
B1, B2, B3, B4: B-EU; C0603
C32, C33, C34, C35, C36, C37, C38, C39, C40, C44, C45, C46, C47, C58, C59, C60, C61, C64, C65: 100nF; C0603
H1: Ground pad for FPGA; 2,8-PAD
IC1: 10CL016YE144C8G; QFP50P2200X2200X165-145N
R33, R34, R36: 10k; R0603

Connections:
50MHZ_OUT: IC1.25 (CLK3); also elsewhere on the board
+1V2: B2.1, B4.1, C65.1; also elsewhere on the board
+2V5: B3.1, C60.1; also elsewhere on the board
+3V3: B1.1, C33.1; also elsewhere on the board
CLK_SCL: IC1.66 (IO_25); also elsewhere on the board
CLK_SDA: IC1.65 (IO_24); also elsewhere on the board
FL_CE: IC1.8 (IO_3); also elsewhere on the board
FL_CLK: IC1.12 (IO_6); also elsewhere on the board
FL_SI: IC1.6 (IO_1); also elsewhere on the board
FL_SO: IC1.13 (IO_7); also elsewhere on the board
GND: C32.2, C33.2, C34.2, C35.2, C36.2, C37.2, C38.2, C39.2, C40.2, C44.2, C45.2, C46.2, C47.2, C58.2, C59.2, C60.2, C61.2, C64.2, C65.2, H1.B2,8, IC1.2 (GNDA3), IC1.4 (GND_1), IC1.19 (GND_2), IC1.21 (NCE), IC1.27 (GND_3), IC1.30 (GND_4), IC1.36 (GNDA1), IC1.41 (GND_5), IC1.48 (GND_6), IC1.57 (GND_7), IC1.63 (GND_8), IC1.64 (GND_9), IC1.74 (GNDA4), IC1.79 (GND_10), IC1.82 (GND_11), IC1.95 (GND_12), IC1.96 (MSEL1), IC1.104 (GND_13), IC1.108 (GNDA2), IC1.110 (GND_14), IC1.118 (GND_15), IC1.123 (GND_16), IC1.131 (GND_17), IC1.140 (GND_18), IC1.145 (GND_19); also elsewhere on the board
GPIO_1: IC1.144 (IO_63); also elsewhere on the board
GPIO_2: IC1.143 (IO_62); also elsewhere on the board
GPIO_3: IC1.142 (IO_61); also elsewhere on the board
GPIO_4: IC1.141 (IO_60); also elsewhere on the board
GPIO_5: IC1.137 (IO_59); also elsewhere on the board
GPIO_6: IC1.136 (IO_58); also elsewhere on the board
GPIO_11: IC1.125 (IO_53); also elsewhere on the board
GPIO_12: IC1.121 (IO_52); also elsewhere on the board
GPIO_13: IC1.120 (IO_51); also elsewhere on the board
GPIO_14: IC1.119 (IO_50); also elsewhere on the board
GPIO_15: IC1.115 (IO_49); also elsewhere on the board
GPIO_16: IC1.114 (IO_48); also elsewhere on the board
GPIO_17: IC1.113 (IO_47); also elsewhere on the board
GPIO_18: IC1.112 (IO_46); also elsewhere on the board
GPIO_19: IC1.111 (IO_45); also elsewhere on the board
GPIO_20: IC1.106 (IO_44); also elsewhere on the board
GPIO_21: IC1.105 (IO_43); also elsewhere on the board
GPIO_22: IC1.100 (IO_40); also elsewhere on the board
GPIO_27: IC1.80 (IO_33); also elsewhere on the board
GPIO_28: IC1.77 (IO_32); also elsewhere on the board
GPIO_29: IC1.76 (IO_31); also elsewhere on the board
GPIO_30: IC1.72 (IO_30); also elsewhere on the board
GPIO_31: IC1.71 (IO_29); also elsewhere on the board
GPIO_32: IC1.69 (IO_28); also elsewhere on the board
GPIO_33: IC1.68 (IO_27); also elsewhere on the board
GPIO_34: IC1.67 (IO_26); also elsewhere on the board
GPI_7: IC1.129 (CLK11); also elsewhere on the board
GPI_8: IC1.128 (CLK10); also elsewhere on the board
GPI_9: IC1.127 (CLK9); also elsewhere on the board
GPI_10: IC1.126 (CLK8); also elsewhere on the board
GPI_23: IC1.91 (CLK4); also elsewhere on the board
GPI_24: IC1.90 (CLK5); also elsewhere on the board
GPI_25: IC1.89 (CLK6); also elsewhere on the board
GPI_26: IC1.88 (CLK7); also elsewhere on the board
HDMI_CEC: IC1.83 (IO_34); also elsewhere on the board
HDMI_CLKN: IC1.98 (IO_38); also elsewhere on the board
HDMI_CLKP: IC1.99 (IO_39); also elsewhere on the board
HDMI_DATA0N: IC1.101 (IO_41); also elsewhere on the board
HDMI_DATA0P: IC1.103 (IO_42); also elsewhere on the board
HDMI_DATA1N: IC1.132 (IO_54); also elsewhere on the board
HDMI_DATA1P: IC1.133 (IO_55); also elsewhere on the board
HDMI_DATA2N: IC1.134 (IO_56); also elsewhere on the board
HDMI_DATA2P: IC1.135 (IO_57); also elsewhere on the board
LED_0: IC1.39 (IO_12); also elsewhere on the board
LED_1: IC1.42 (IO_13); also elsewhere on the board
LED_2: IC1.43 (IO_14); also elsewhere on the board
LED_3: IC1.44 (IO_15); also elsewhere on the board
LED_4: IC1.46 (IO_16); also elsewhere on the board
LED_5: IC1.49 (IO_17); also elsewhere on the board
LED_6: IC1.50 (IO_18); also elsewhere on the board
LED_7: IC1.51 (IO_19); also elsewhere on the board
unnamed: IC1.9 (NSTATUS), R33.2
unnamed: IC1.14 (NCONFIG), R34.2
unnamed: IC1.92 (CONF_DONE), R36.1
PLL_CLK0: IC1.22 (CLK0); also elsewhere on the board
PLL_CLK1: IC1.23 (CLK1); also elsewhere on the board
PLL_CLK2: IC1.24 (CLK2); also elsewhere on the board
RESET: IC1.28 (IO_8); also elsewhere on the board
RGB_B: IC1.7 (IO_2); also elsewhere on the board
RGB_G: IC1.11 (IO_5); also elsewhere on the board
RGB_R: IC1.10 (IO_4); also elsewhere on the board
RS485_DIR: IC1.33 (IO_11); also elsewhere on the board
RS485_RX: IC1.31 (IO_9); also elsewhere on the board
RS485_TX: IC1.32 (IO_10); also elsewhere on the board
SWS_0: IC1.55 (CLK12); also elsewhere on the board
SWS_1: IC1.54 (CLK13); also elsewhere on the board
SWS_2: IC1.53 (CLK14); also elsewhere on the board
SWS_3: IC1.52 (CLK15); also elsewhere on the board
SW_0: IC1.61 (IO_23); also elsewhere on the board
SW_1: IC1.60 (IO_22); also elsewhere on the board
SW_2: IC1.59 (IO_21); also elsewhere on the board
SW_3: IC1.58 (IO_20); also elsewhere on the board
TCK: IC1.16 (TCK); also elsewhere on the board
TDI: IC1.15 (TDI); also elsewhere on the board
TDO: IC1.20 (TDO); also elsewhere on the board
TMS: IC1.18 (TMS); also elsewhere on the board
USB_D+: IC1.86 (IO_36); also elsewhere on the board
USB_D-: IC1.85 (IO_35); also elsewhere on the board
USB_ID: IC1.87 (IO_37); also elsewhere on the board
VCCA: B3.2, C58.1, C59.1, IC1.3 (VCCA3), IC1.35 (VCCA1), IC1.75 (VCCA4), IC1.94 (MSEL0), IC1.97 (MSEL2), IC1.107 (VCCA2)
VCCD: B4.2, C61.1, C64.1, IC1.1 (VCCD_PLL3), IC1.37 (VCCD_PLL1), IC1.73 (VCCD_PLL4)
VCCINT: B2.2, C44.1, C45.1, C46.1, C47.1, IC1.5 (VCCINT_1), IC1.29 (VCCINT_2), IC1.34 (VCCINT_3), IC1.38 (VCCINT_4), IC1.45 (VCCINT_5), IC1.70 (VCCINT_6), IC1.78 (VCCINT_7), IC1.84 (VCCINT_8), IC1.102 (VCCINT_9), IC1.116 (VCCINT_10), IC1.124 (VCCINT_11), IC1.138 (VCCINT_12)
VCCIO: B1.2, C32.1, C34.1, C35.1, C36.1, C37.1, C38.1, C39.1, C40.1, IC1.17 (VCCIO1), IC1.26 (VCCIO2), IC1.40 (VCCIO3_1), IC1.47 (VCCIO3_2), IC1.56 (VCCIO4_1), IC1.62 (VCCIO4_2), IC1.81 (VCCIO5), IC1.93 (VCCIO6), IC1.117 (VCCIO7_1), IC1.122 (VCCIO7_2), IC1.130 (VCCIO8_1), IC1.139 (VCCIO8_2), R33.1, R34.1, R36.2

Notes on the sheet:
10CL016YE144C8G
ASx1 MSEL 101 3V3 Fast
Design: D.Keekstra

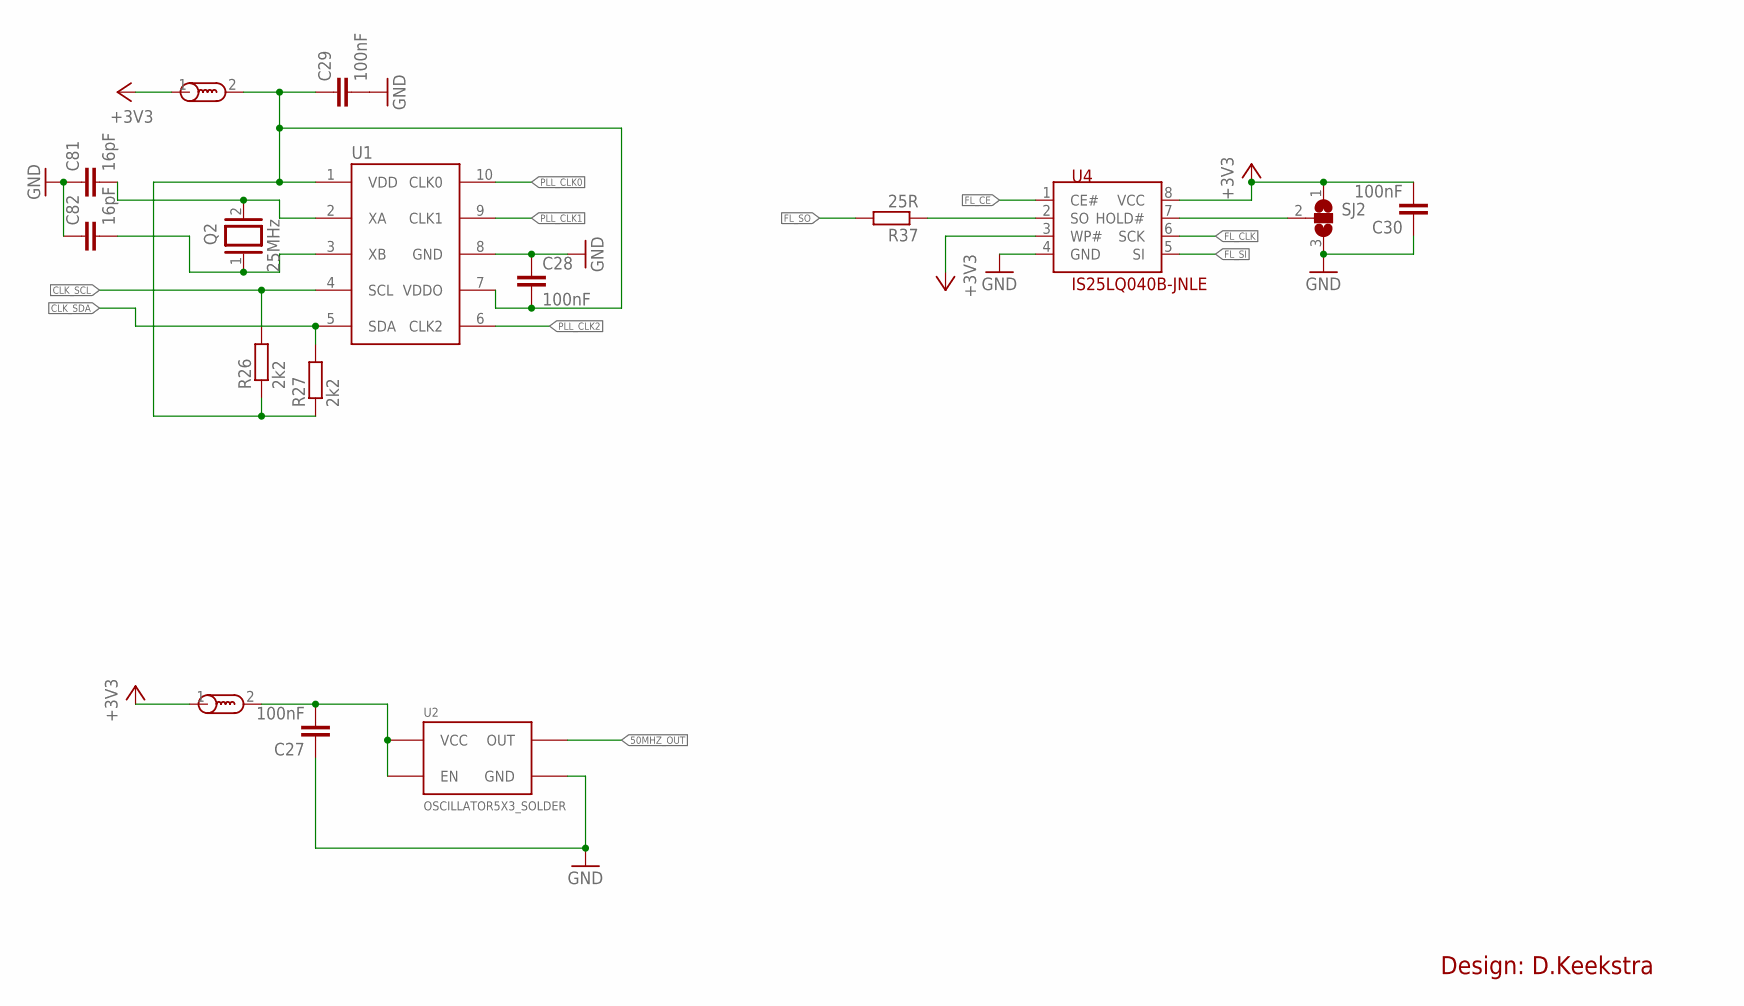
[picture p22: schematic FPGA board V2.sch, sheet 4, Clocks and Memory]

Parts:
B5, B6: B-EU; C0603
C27, C28, C29, C30: 100nF; C0603
C81, C82: 16pF; C0603
Q2: 25MHz; QS
R26, R27: 2k2; R0603
R37: 25R; R0603
SJ2: SJ2W; SJ_2
U1: SI5351A_CLOCK_GEN; MSOP-10
U2: OSCILLATOR5X3_SOLDER; CRYSTAL-SMD-5X3_SOLDER
U4: IS25LQ040B-JNLE; SOIC8

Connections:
50MHZ_OUT: U2.3 (OUT); also elsewhere on the board
+3V3: B5.1, B6.1, C30.2, SJ2.1, U4.3 (WP#), U4.8 (VCC); also elsewhere on the board
CLK_SCL: R26.2, U1.4 (SCL); also elsewhere on the board
CLK_SDA: R27.2, U1.5 (SDA); also elsewhere on the board
FL_CE: U4.1 (CE#); also elsewhere on the board
FL_CLK: U4.6 (SCK); also elsewhere on the board
FL_SI: U4.5 (SI); also elsewhere on the board
FL_SO: R37.2; also elsewhere on the board
GND: C27.1, C28.1, C29.2, C30.1, C81.1, C82.1, SJ2.3, U1.8 (GND), U2.2 (GND), U4.4 (GND); also elsewhere on the board
unnamed: C82.2, Q2.1, U1.3 (XB)
unnamed: C81.2, Q2.2, U1.2 (XA)
unnamed: SJ2.2, U4.7 (HOLD#)
unnamed: B6.2, C28.2, C29.1, R26.1, R27.1, U1.1 (VDD), U1.7 (VDDO)
unnamed: B5.2, C27.2, U2.1 (EN), U2.4 (VCC)
PLL_CLK0: U1.10 (CLK0); also elsewhere on the board
PLL_CLK1: U1.9 (CLK1); also elsewhere on the board
PLL_CLK2: U1.6 (CLK2); also elsewhere on the board
SO: R37.1, U4.2 (SO)

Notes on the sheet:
Design: D.Keekstra

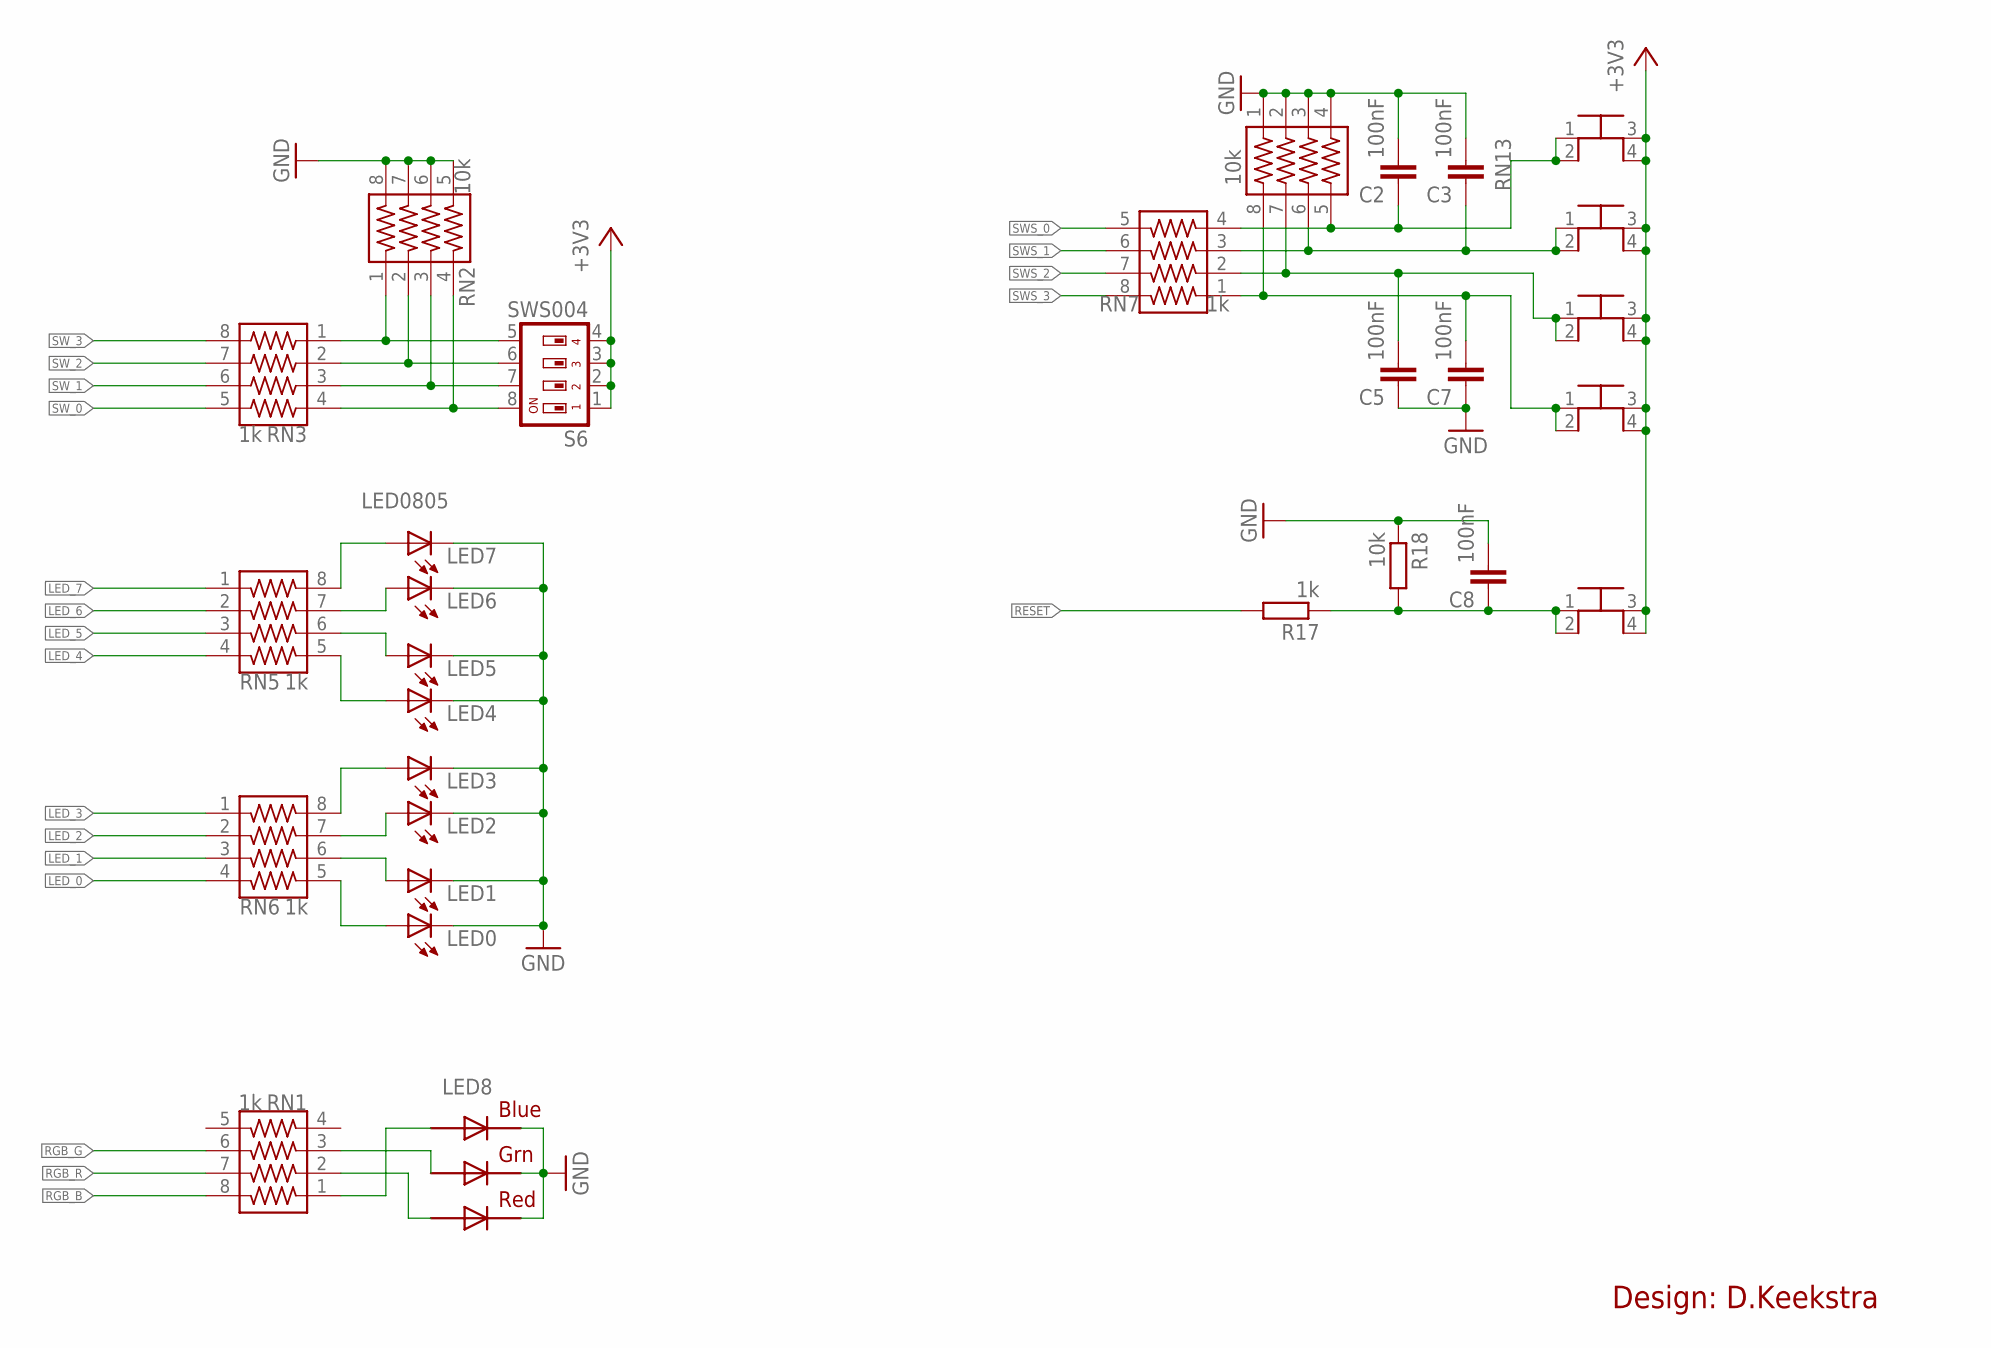
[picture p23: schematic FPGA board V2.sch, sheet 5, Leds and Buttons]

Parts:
C2, C3, C5, C7, C8: 100nF; C0603
LED0, LED1, LED2, LED3, LED4, LED5, LED6, LED7: LED0805; CHIPLED_0805
LED8: RGBLED5050
R17: 1k; R0603
R18: 10k; R0603
RN1, RN3, RN5, RN6, RN7: 1k; 744-8NS
RN2, RN13: 10k; 744-8NS
S1, S2, S3, S4, S5: SKQGADE010; SKQGAKE010
S6: SWS004; SMS-004

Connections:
+3V3: S1.3, S1.4, S2.3, S2.4, S3.3, S3.4, S4.3, S4.4, S5.3, S5.4, S6.1, S6.2, S6.3, S6.4; also elsewhere on the board
GND: C2.2, C3.2, C5.1, C7.1, C8.2, LED0.C, LED1.C, LED2.C, LED3.C, LED4.C, LED5.C, LED6.C, LED7.C, LED8.4 (BLUE_C), LED8.5 (RED_C), LED8.6 (GREEN_C), R18.1, RN2.5, RN2.6, RN2.7, RN2.8, RN13.1, RN13.2, RN13.3, RN13.4; also elsewhere on the board
LED_0: RN6.4; also elsewhere on the board
LED_1: RN6.3; also elsewhere on the board
LED_2: RN6.2; also elsewhere on the board
LED_3: RN6.1; also elsewhere on the board
LED_4: RN5.4; also elsewhere on the board
LED_5: RN5.3; also elsewhere on the board
LED_6: RN5.2; also elsewhere on the board
LED_7: RN5.1; also elsewhere on the board
unnamed: RN2.3, RN3.3, S6.7
unnamed: RN2.1, RN3.1, S6.5
unnamed: RN2.2, RN3.2, S6.6
unnamed: RN2.4, RN3.4, S6.8
unnamed: LED7.A, RN5.8
unnamed: LED6.A, RN5.7
unnamed: LED5.A, RN5.6
unnamed: LED4.A, RN5.5
unnamed: LED3.A, RN6.8
unnamed: LED2.A, RN6.7
unnamed: LED1.A, RN6.6
unnamed: LED0.A, RN6.5
unnamed: LED8.1 (GREEN_A), RN1.3
unnamed: LED8.2 (RED_A), RN1.2
unnamed: LED8.3 (BLUE_A), RN1.1
unnamed: C2.1, RN7.4, RN13.5, S4.1, S4.2
unnamed: C3.1, RN7.3, RN13.6, S3.1, S3.2
unnamed: C5.2, RN7.2, RN13.7, S2.1, S2.2
unnamed: C7.2, RN7.1, RN13.8, S1.1, S1.2
unnamed: C8.1, R17.1, R18.2, S5.1, S5.2
RESET: R17.2; also elsewhere on the board
RGB_B: RN1.8; also elsewhere on the board
RGB_G: RN1.6; also elsewhere on the board
RGB_R: RN1.7; also elsewhere on the board
SWS_0: RN7.5; also elsewhere on the board
SWS_1: RN7.6; also elsewhere on the board
SWS_2: RN7.7; also elsewhere on the board
SWS_3: RN7.8; also elsewhere on the board
SW_0: RN3.5; also elsewhere on the board
SW_1: RN3.6; also elsewhere on the board
SW_2: RN3.7; also elsewhere on the board
SW_3: RN3.8; also elsewhere on the board

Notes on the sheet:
Design: D.Keekstra

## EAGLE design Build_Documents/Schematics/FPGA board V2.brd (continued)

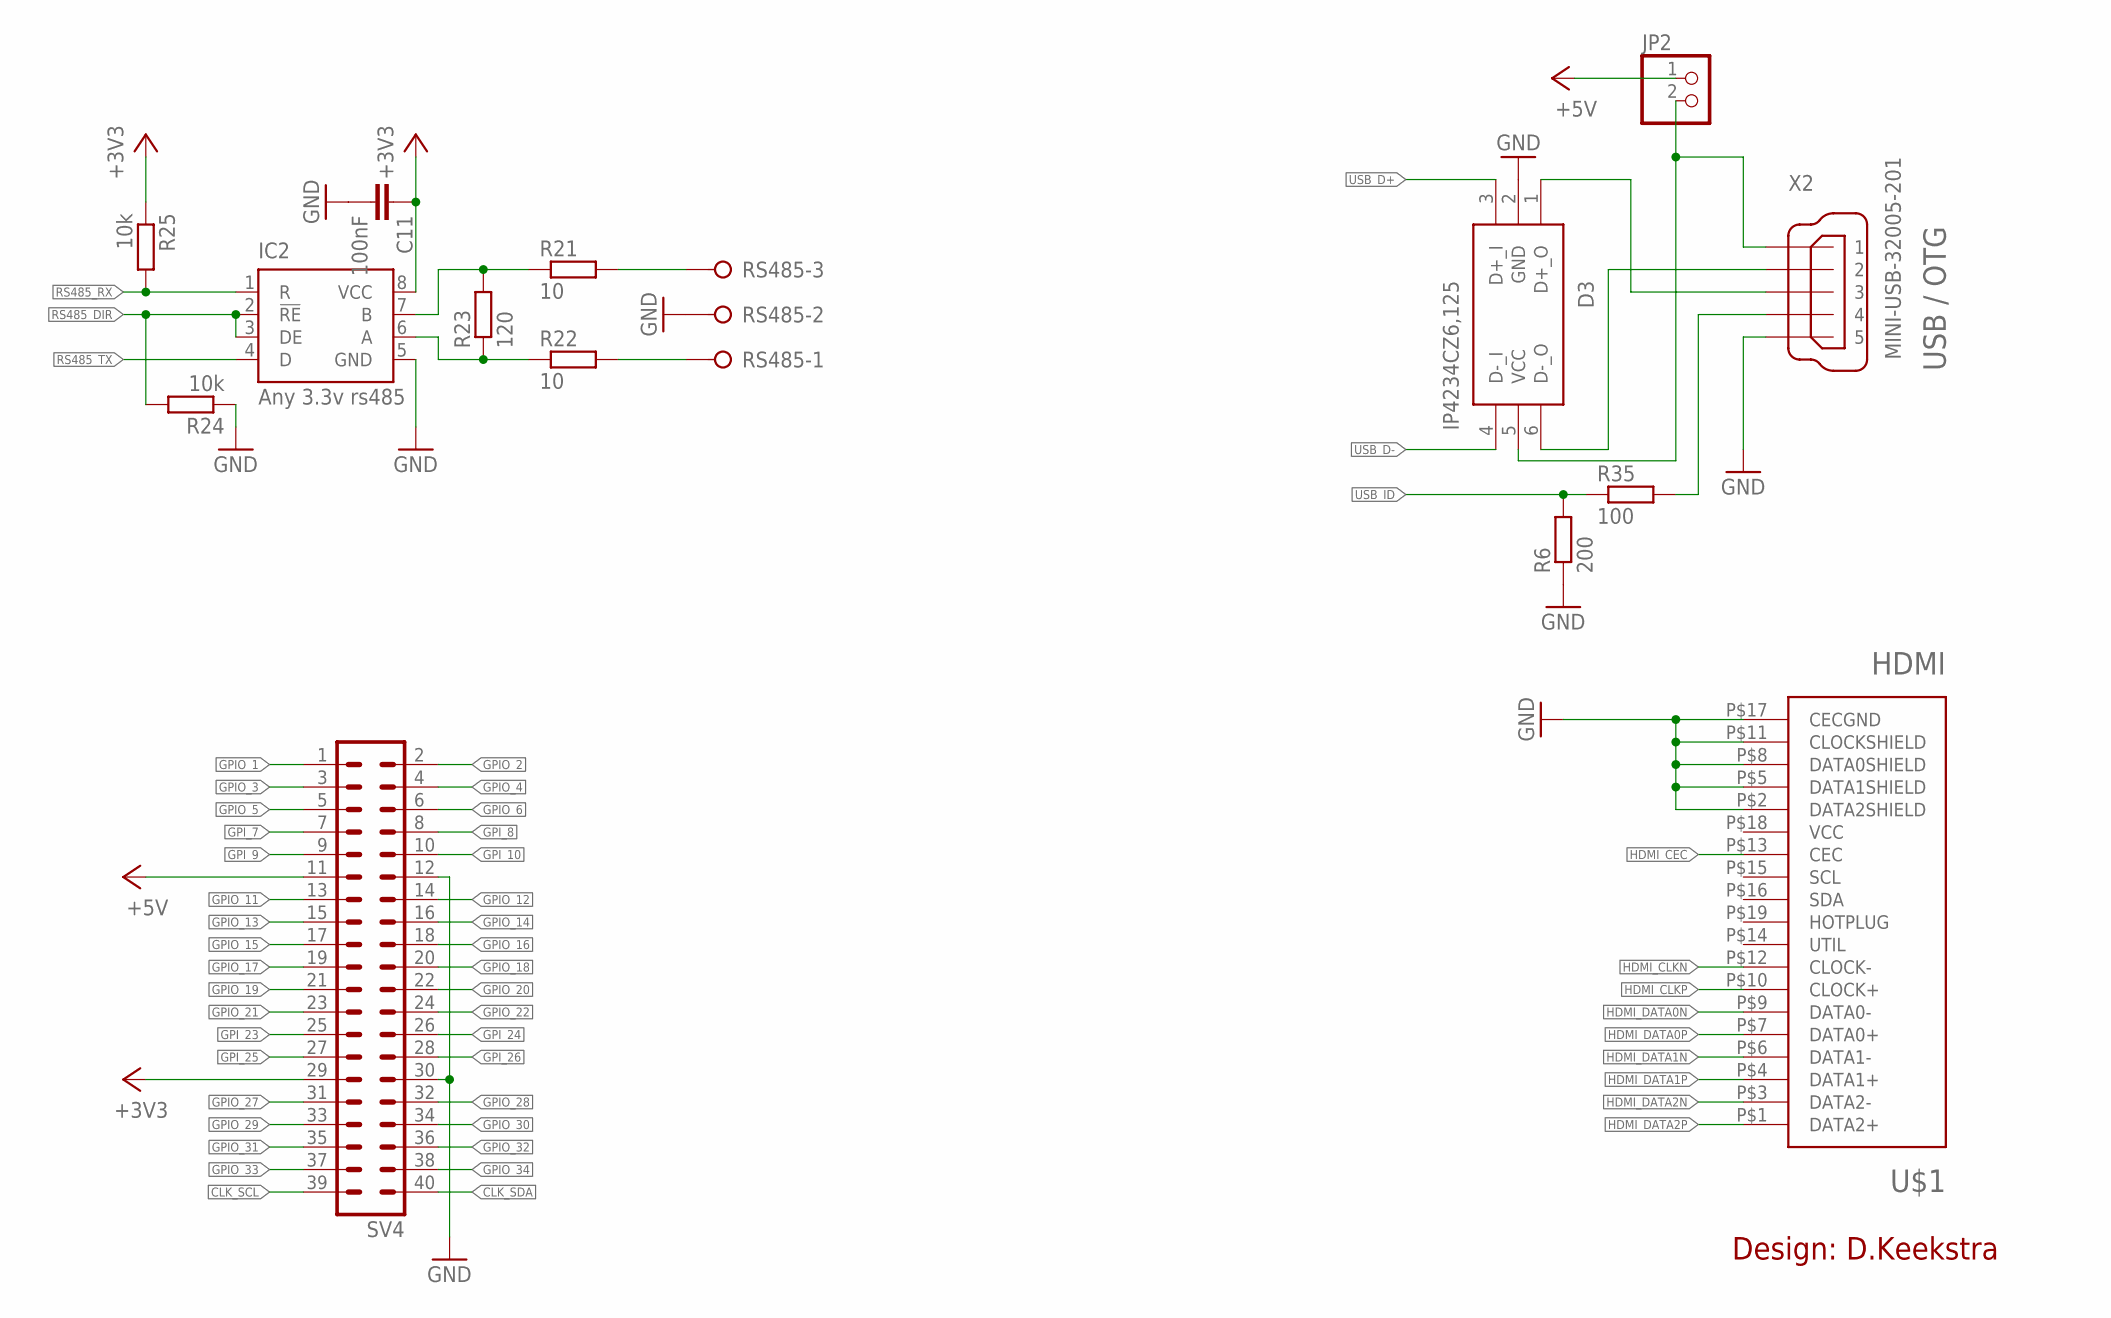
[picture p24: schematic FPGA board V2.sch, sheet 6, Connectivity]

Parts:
C11: 100nF; C0603
D3: IP4234CZ6,125; SOT95P275X110-6N
IC2: Any 3.3v rs485; SO-08
JP2: PINHD-1X2; 1X02
R6: 200; R0603
R21, R22: 10; R0603
R23: 120; R0603
R24, R25: 10k; R0603
R35: 100; R0603
RS485: W237-3E
SV4: MA20-2
U$1: HDMI; HDMI_A
X2: MINI-USB-32005-201; 32005-201

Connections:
+3V3: C11.1, IC2.8 (VCC), R25.1, SV4.29; also elsewhere on the board
+5V: JP2.1, SV4.11; also elsewhere on the board
CLK_SCL: SV4.39; also elsewhere on the board
CLK_SDA: SV4.40; also elsewhere on the board
GND: C11.2, D3.2 (GND), IC2.5 (GND), R6.1, R24.1, RS485.2, SV4.12, SV4.30, U$1.P$2 (DATA2SHIELD), U$1.P$5 (DATA1SHIELD), U$1.P$8 (DATA0SHIELD), U$1.P$11 (CLOCKSHIELD), U$1.P$17 (CECGND), X2.5; also elsewhere on the board
GPIO_1: SV4.1; also elsewhere on the board
GPIO_2: SV4.2; also elsewhere on the board
GPIO_3: SV4.3; also elsewhere on the board
GPIO_4: SV4.4; also elsewhere on the board
GPIO_5: SV4.5; also elsewhere on the board
GPIO_6: SV4.6; also elsewhere on the board
GPIO_11: SV4.13; also elsewhere on the board
GPIO_12: SV4.14; also elsewhere on the board
GPIO_13: SV4.15; also elsewhere on the board
GPIO_14: SV4.16; also elsewhere on the board
GPIO_15: SV4.17; also elsewhere on the board
GPIO_16: SV4.18; also elsewhere on the board
GPIO_17: SV4.19; also elsewhere on the board
GPIO_18: SV4.20; also elsewhere on the board
GPIO_19: SV4.21; also elsewhere on the board
GPIO_20: SV4.22; also elsewhere on the board
GPIO_21: SV4.23; also elsewhere on the board
GPIO_22: SV4.24; also elsewhere on the board
GPIO_27: SV4.31; also elsewhere on the board
GPIO_28: SV4.32; also elsewhere on the board
GPIO_29: SV4.33; also elsewhere on the board
GPIO_30: SV4.34; also elsewhere on the board
GPIO_31: SV4.35; also elsewhere on the board
GPIO_32: SV4.36; also elsewhere on the board
GPIO_33: SV4.37; also elsewhere on the board
GPIO_34: SV4.38; also elsewhere on the board
GPI_7: SV4.7; also elsewhere on the board
GPI_8: SV4.8; also elsewhere on the board
GPI_9: SV4.9; also elsewhere on the board
GPI_10: SV4.10; also elsewhere on the board
GPI_23: SV4.25; also elsewhere on the board
GPI_24: SV4.26; also elsewhere on the board
GPI_25: SV4.27; also elsewhere on the board
GPI_26: SV4.28; also elsewhere on the board
HDMI_CEC: U$1.P$13 (CEC); also elsewhere on the board
HDMI_CLKN: U$1.P$12 (CLOCK-); also elsewhere on the board
HDMI_CLKP: U$1.P$10 (CLOCK+); also elsewhere on the board
HDMI_DATA0N: U$1.P$9 (DATA0-); also elsewhere on the board
HDMI_DATA0P: U$1.P$7 (DATA0+); also elsewhere on the board
HDMI_DATA1N: U$1.P$6 (DATA1-); also elsewhere on the board
HDMI_DATA1P: U$1.P$4 (DATA1+); also elsewhere on the board
HDMI_DATA2N: U$1.P$3 (DATA2-); also elsewhere on the board
HDMI_DATA2P: U$1.P$1 (DATA2+); also elsewhere on the board
unnamed: D3.6 (D-_O), X2.2
unnamed: D3.1 (D+_O), X2.3
unnamed: D3.5 (VCC), JP2.2, X2.1
unnamed: IC2.7 (B), R21.1, R23.2
unnamed: IC2.6 (A), R22.1, R23.1
unnamed: R22.2, RS485.1
unnamed: R21.2, RS485.3
unnamed: R35.2, X2.4
RS485_DIR: IC2.2 (!RE), IC2.3 (DE), R24.2; also elsewhere on the board
RS485_RX: IC2.1 (R), R25.2; also elsewhere on the board
RS485_TX: IC2.4 (D); also elsewhere on the board
USB_D+: D3.3 (D+_I); also elsewhere on the board
USB_D-: D3.4 (D-_I); also elsewhere on the board
USB_ID: R6.2, R35.1; also elsewhere on the board

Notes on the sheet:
USB / OTG
Design: D.Keekstra

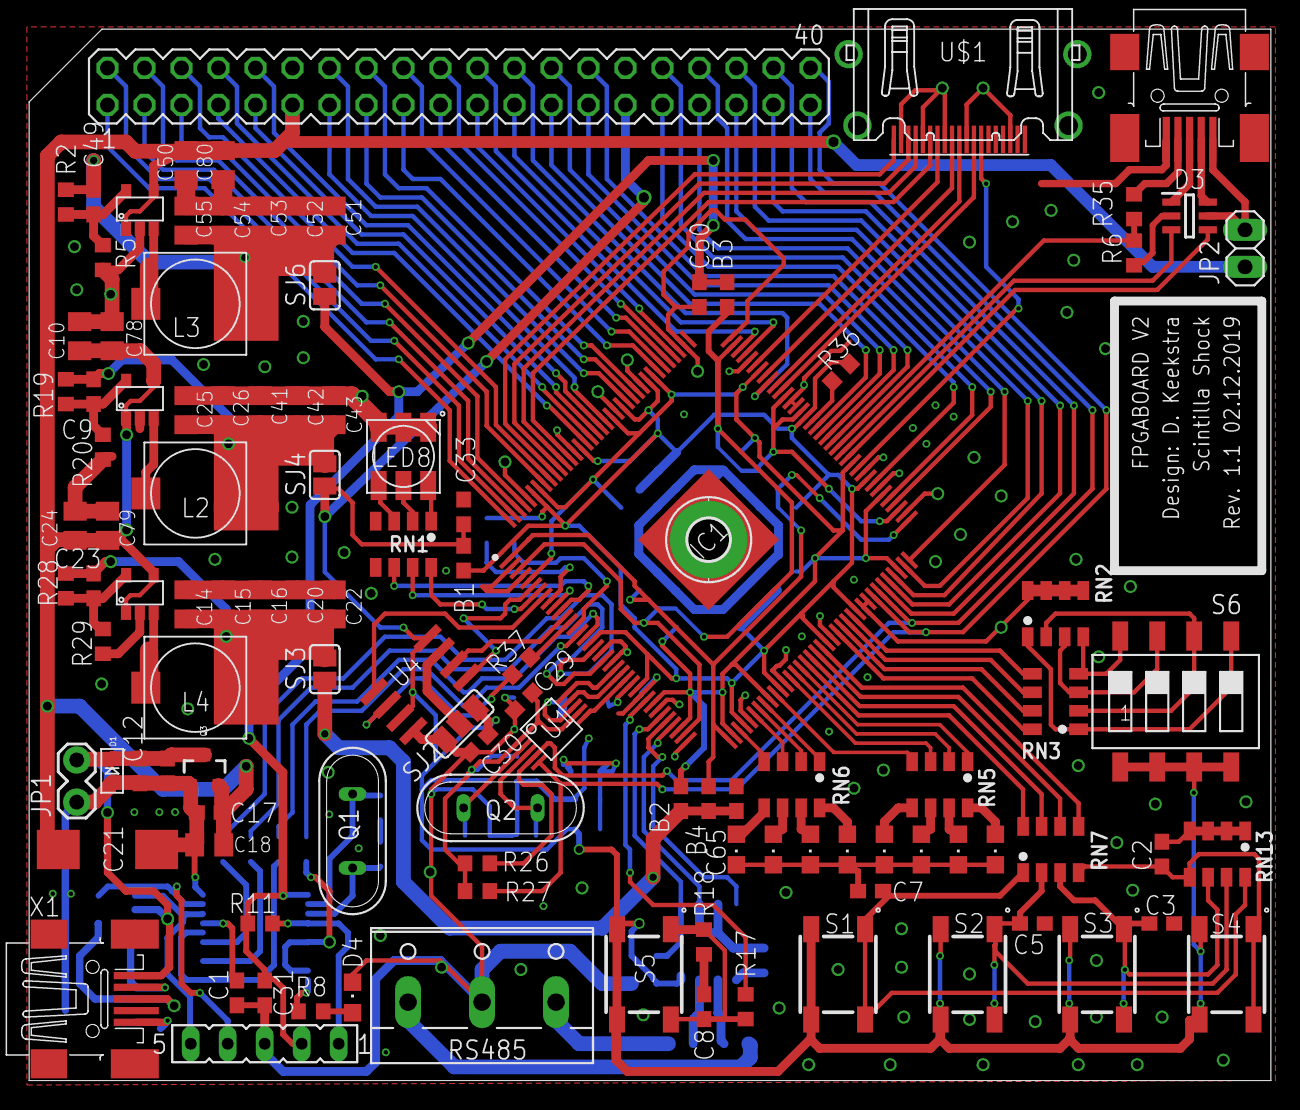
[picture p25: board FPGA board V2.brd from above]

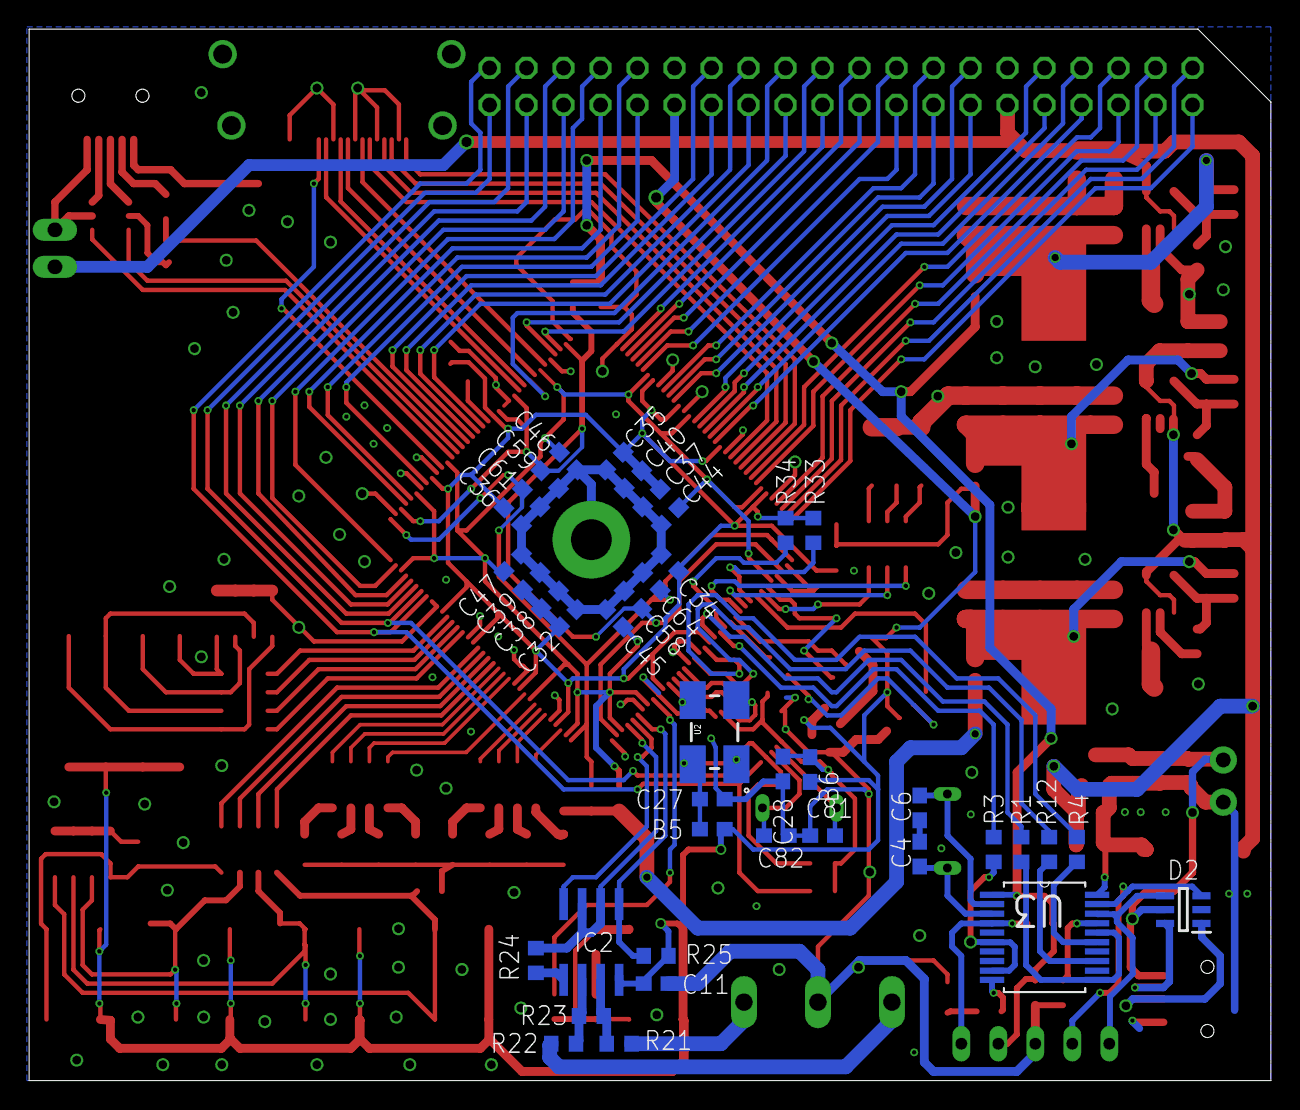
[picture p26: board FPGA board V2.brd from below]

Board: 2 copper layers, 85.3 x 72.2 mm, 151 parts (40 on the bottom side), 153 nets.

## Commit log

2019-12-10 Add image of the board
2019-12-10 Update bom
    [BOM.xlsx]
2019-12-10 Print partlist
    [Printeble SMD partlist.xlsx]
2019-12-19 demosoftware edited by Bert Molenkamp
    removed the synopsys (non-IEEE libraries): std_logic_arith and std_logic_unsigned
    in "case sws is" you alread know that sws(0) is '1' so with that information rgbc<=ses(3 downto 1)
    increment of rgbc can be replaced with MOD 2**length
    same for bugc

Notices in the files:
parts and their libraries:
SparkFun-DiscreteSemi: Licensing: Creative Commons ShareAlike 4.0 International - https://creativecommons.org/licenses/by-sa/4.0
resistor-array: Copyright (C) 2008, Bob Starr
